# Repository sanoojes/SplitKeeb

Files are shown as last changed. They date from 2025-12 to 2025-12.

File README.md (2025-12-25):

# SplitKeeb

A split keyboard for my daily use.

## CAD

will be updated soon.

## PCB

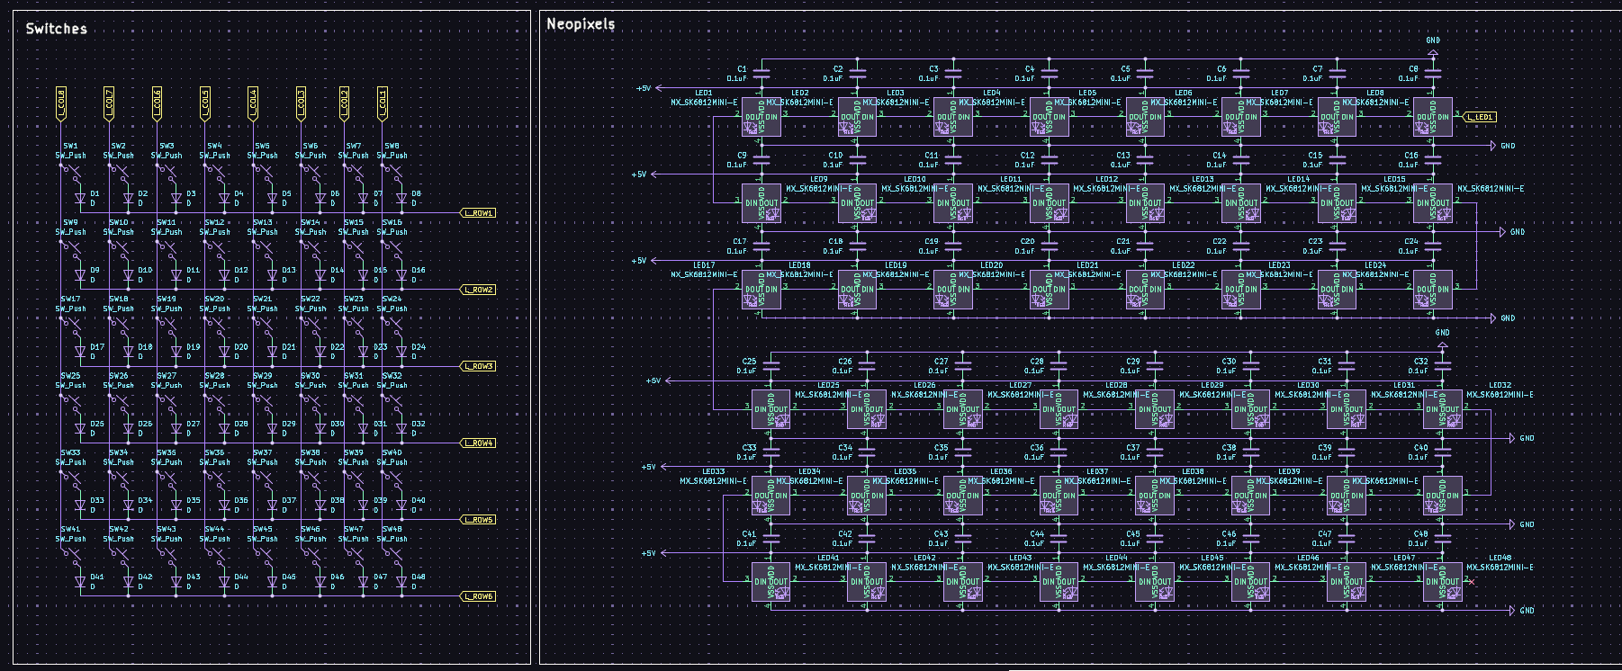
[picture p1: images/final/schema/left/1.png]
left 1
Schematics Left 
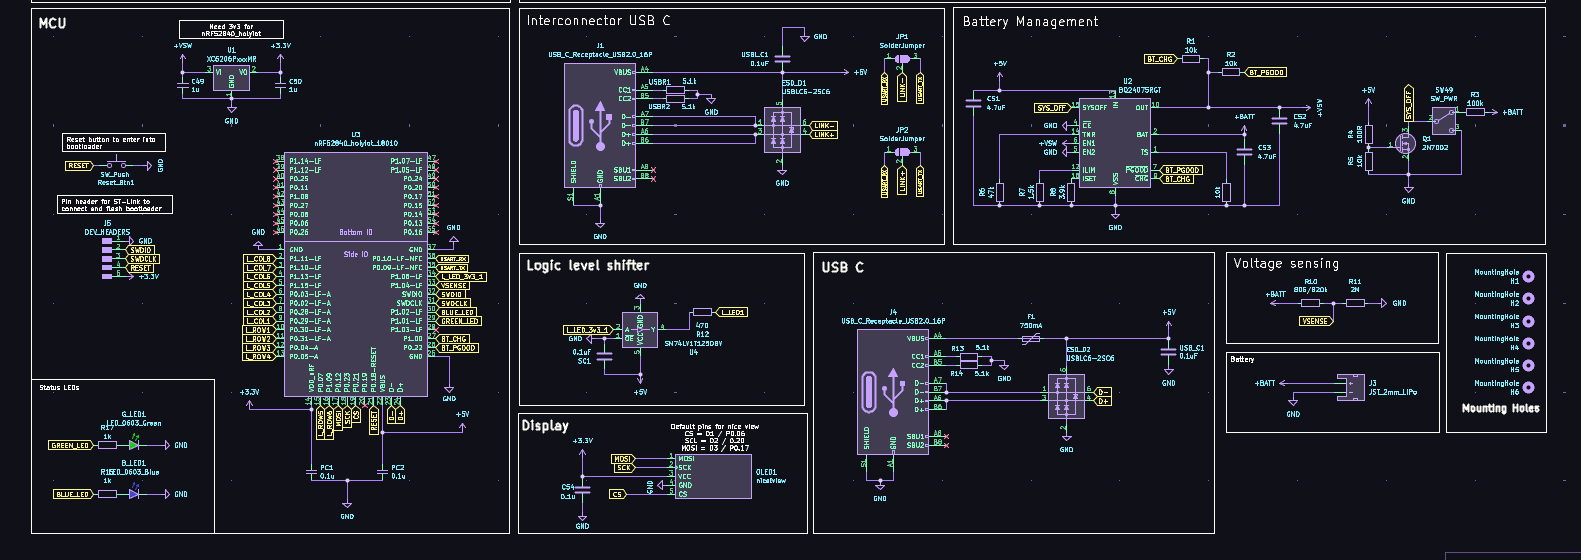
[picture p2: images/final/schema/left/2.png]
left 2


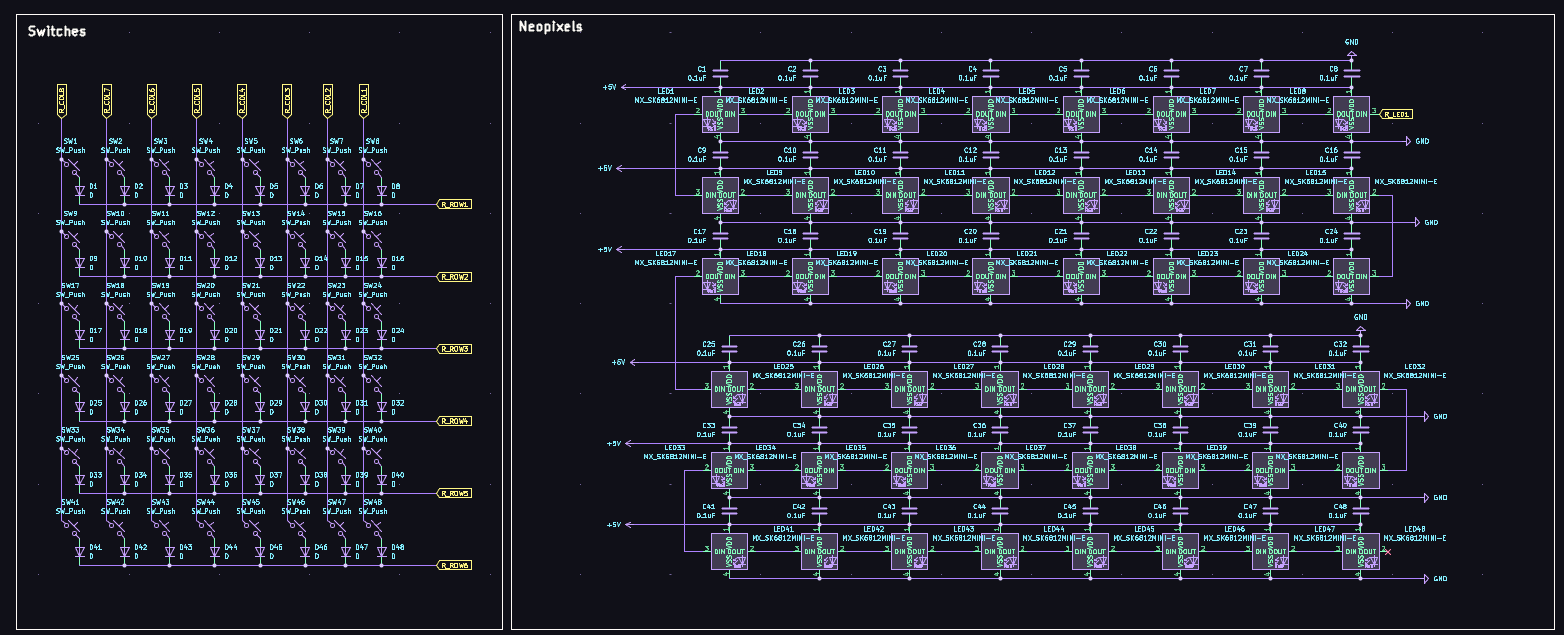
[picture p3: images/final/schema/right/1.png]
right 1
Schematics Right 
right 1

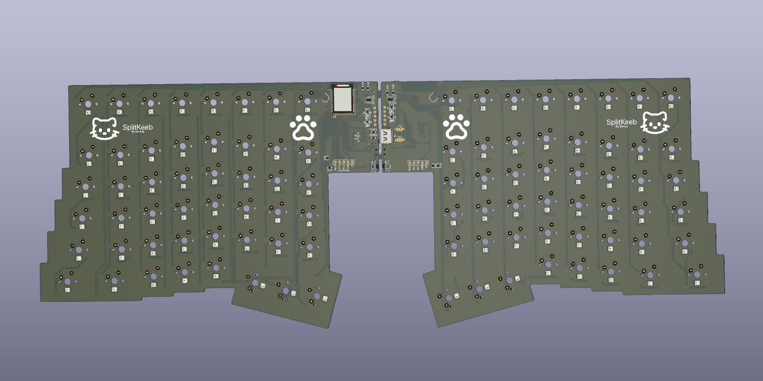
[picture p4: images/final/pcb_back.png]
pcb_back
Renders 
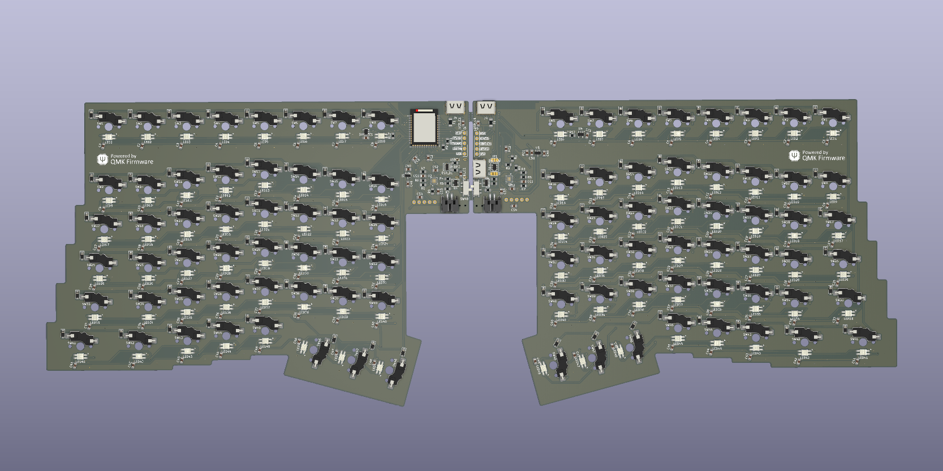
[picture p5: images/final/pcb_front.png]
pcb_front


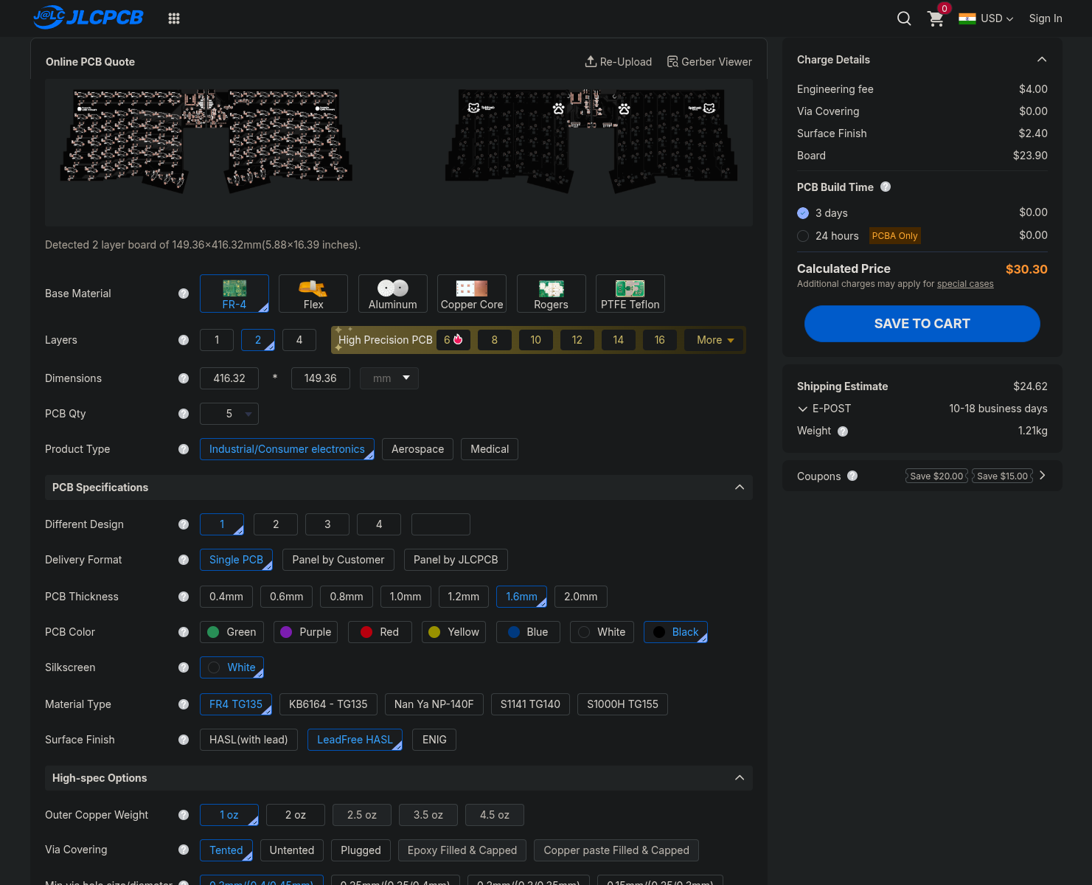
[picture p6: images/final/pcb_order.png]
pcb_order
JLC order

## Firmware

Firmware available at [firmware/](firmware/) firmware will be tweaked and
created after i get the materials/get approved.

### Bill of Materials

Checkout [BOM.csv](bom/SplitKeeb.csv)

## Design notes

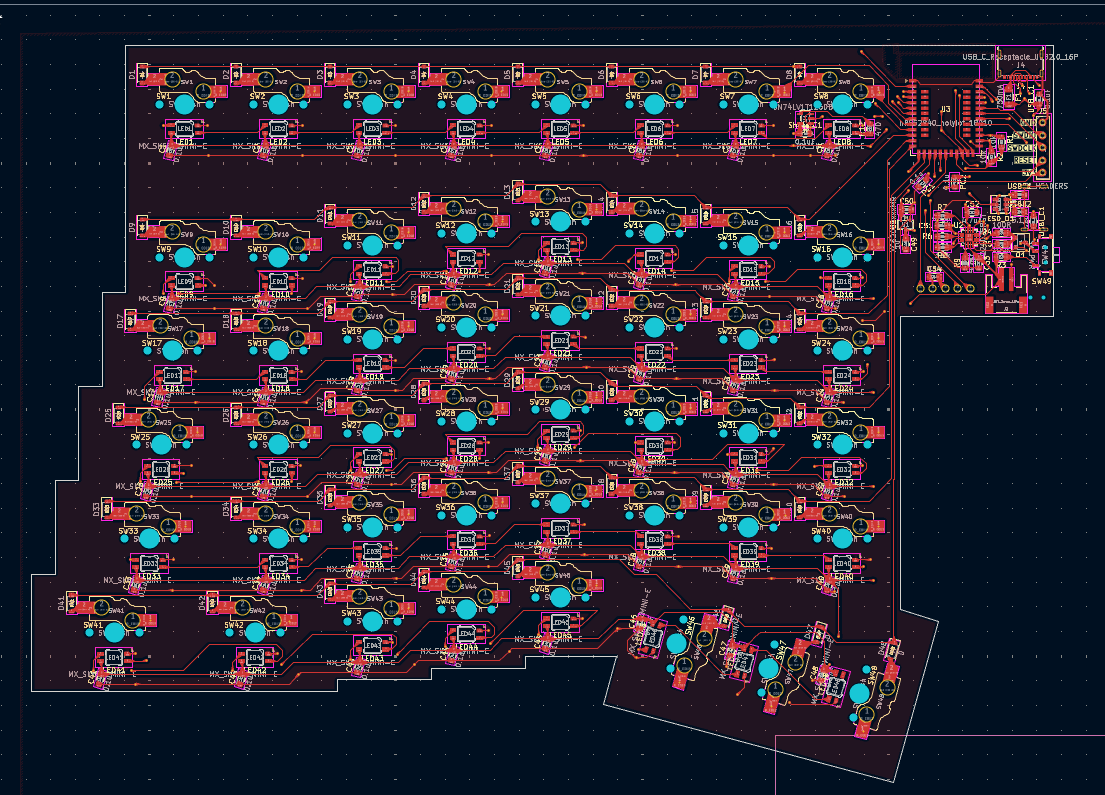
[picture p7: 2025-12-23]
images/day7/pcb2.png

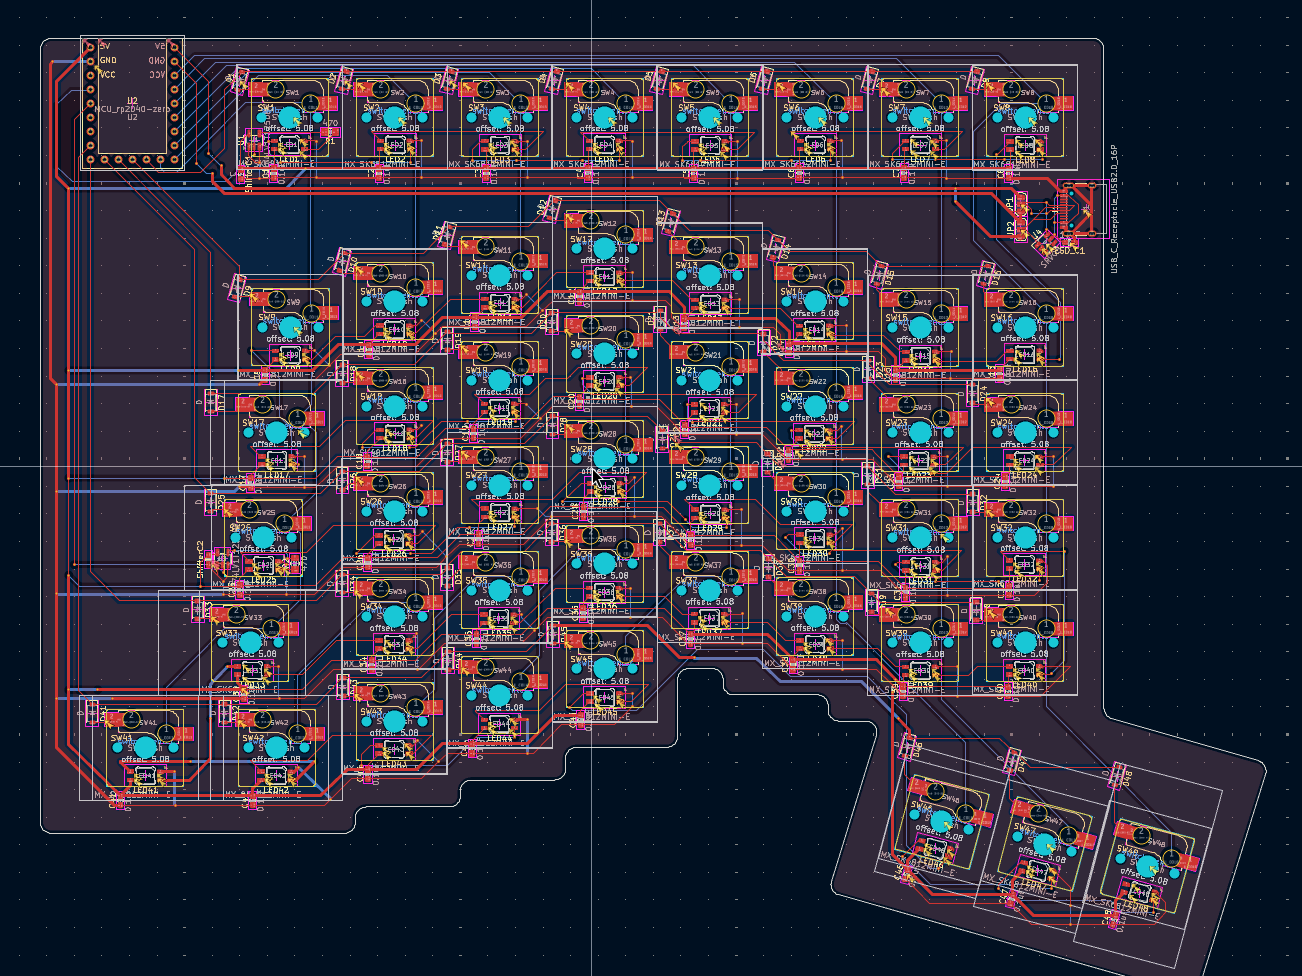
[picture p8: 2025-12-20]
images/day5/pcb_full.png

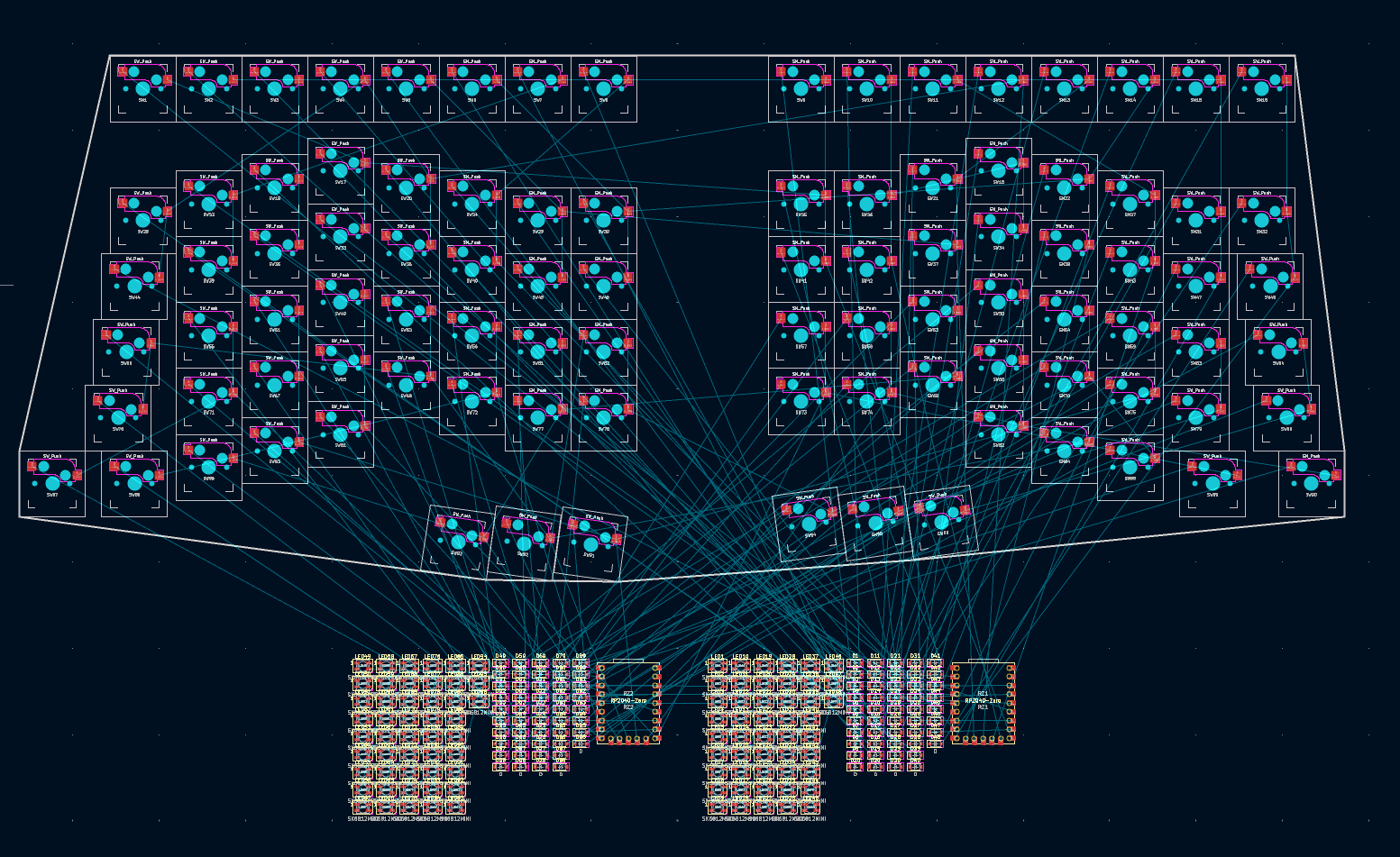
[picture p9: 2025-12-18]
images/day3/kbplacer.png

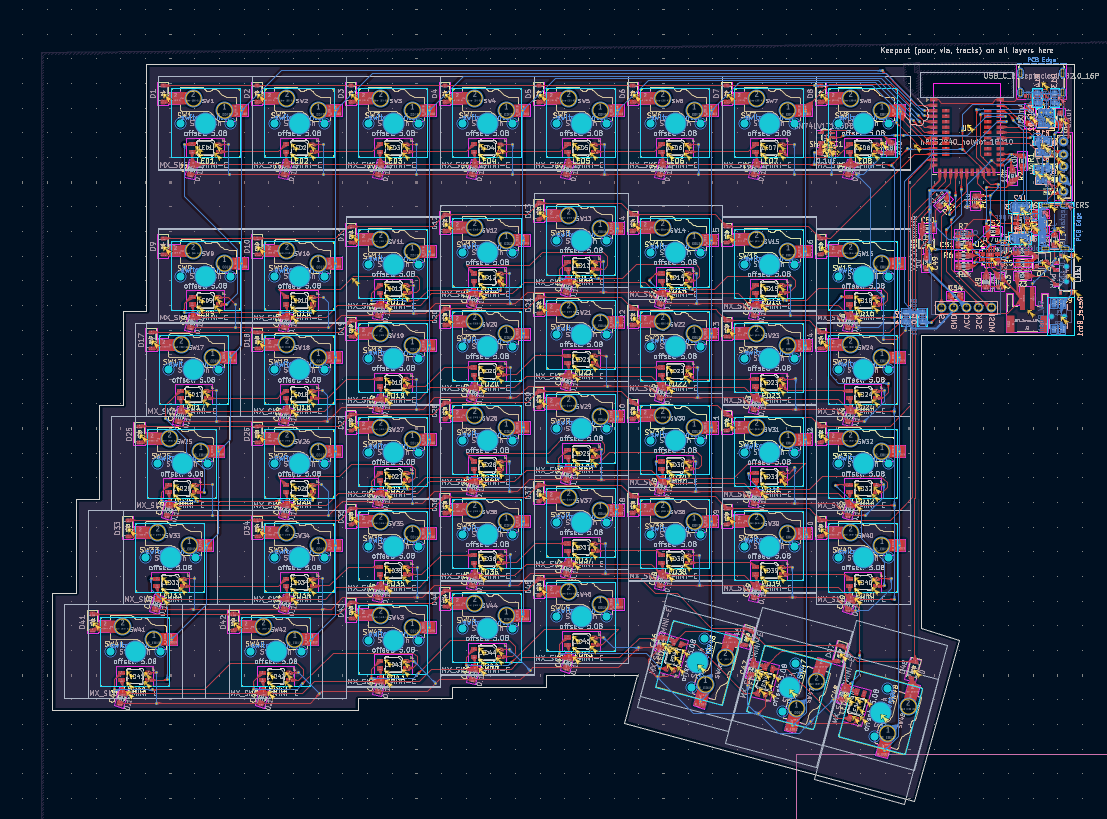
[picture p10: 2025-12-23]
images/day7/image.png

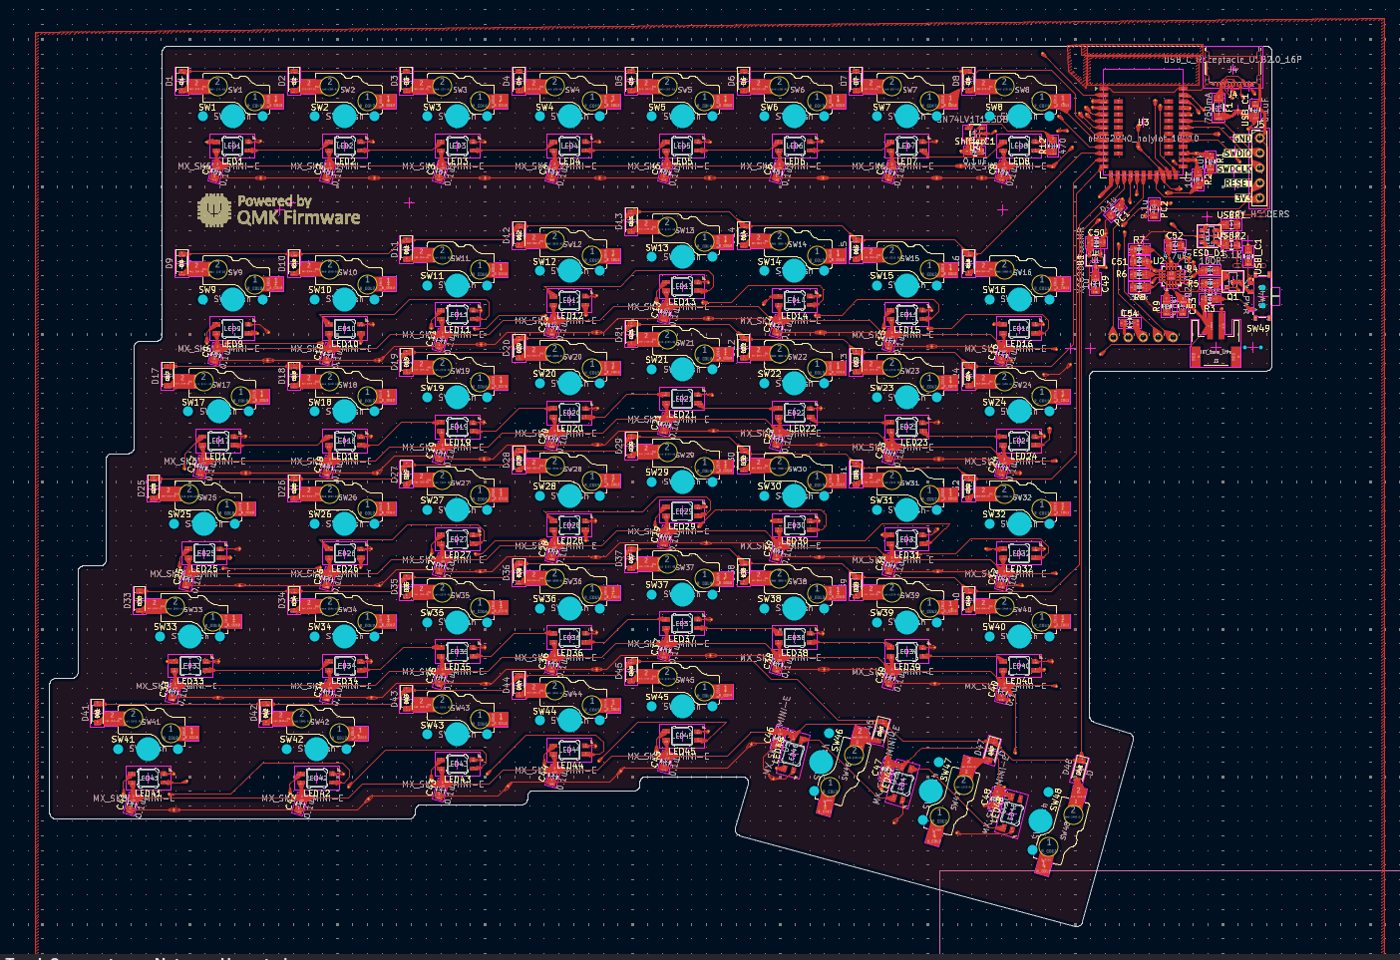
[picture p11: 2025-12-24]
images/day8/front_pcb.png

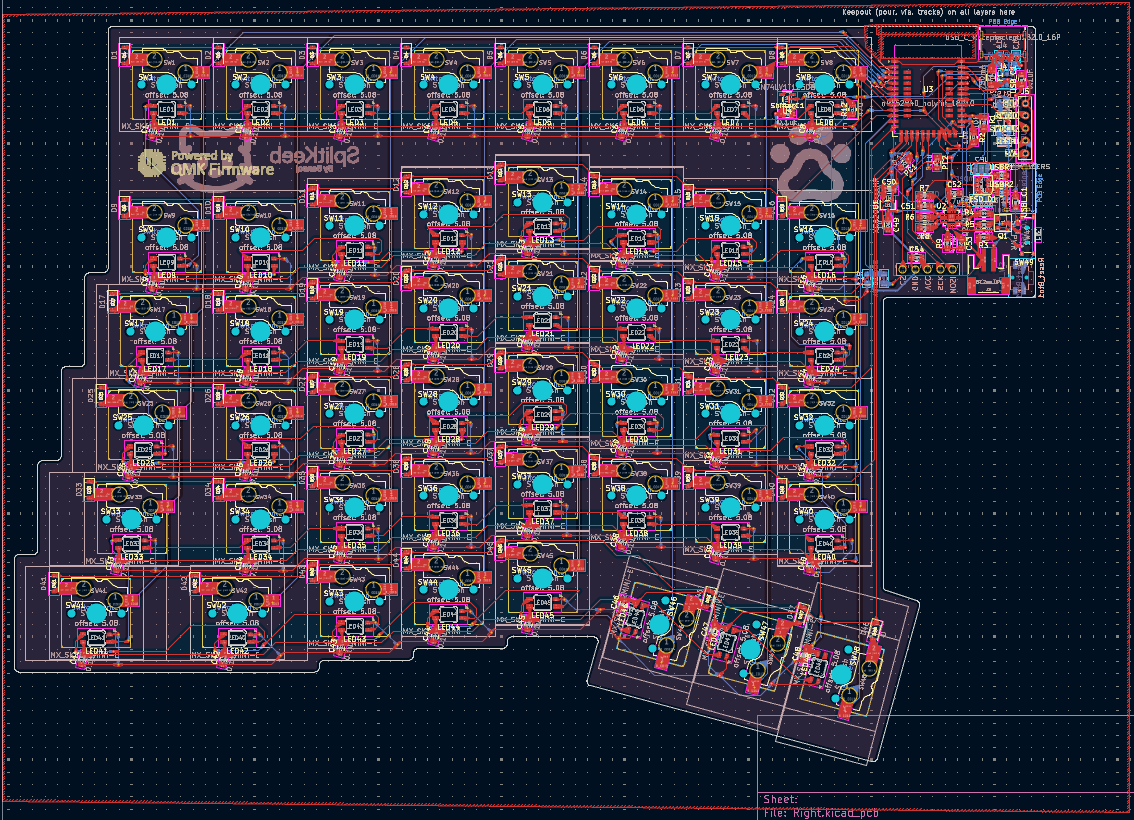
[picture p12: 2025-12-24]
images/day8/full_pcb.png

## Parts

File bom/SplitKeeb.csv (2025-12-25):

Item | Description | Note | Order Quantity | Unit Price | Total Price | URL | URL 2 | URL 3
0.1uF Capacitor | Decoupling Capacitors |  | 120 | ₹0.98 | ₹117.60 | https://robu.in/product/cl21b104kafnnne-samsang-25v-100nf-x7r-%c2%b110-0805-multilayer-ceramic-capacitors-mlcc-smd-smt-rohs/ | https://sharvielectronics.com/product/0-1uf-100nf-50v-capacitor-%c2%b110-tolerance-cc0805kkx7r9bb104-0805-package/
4.7uF Capacitor | Decoupling Capacitors |  | 8 | ₹0.80 | ₹6.40 | https://robu.in/product/cl21a475kpfnnne-samsang-10v-4-7uf-x5r-%C2%B110-0805-multilayer-ceramic-capacitors-mlcc-smd-smt-rohs/ | https://sharvielectronics.com/product/4-7uf-4700nf-25v-capacitor-%c2%b110-tolerance-0805x475k250ct-0805-package/
1uF Capacitor | Decoupling Capacitors |  | 8 | ₹0.70 | ₹5.60 | https://robu.in/product/cl21b105kofnfne-samsang-16v-1uf-x7r-%c2%b110-0805-multilayer-ceramic-capacitors-mlcc-smd-smt-rohs/ | https://sharvielectronics.com/product/1uf-1000nf-50v-capacitor-%c2%b110-tolerance-cc0805kkx7r9bb105-0805-package/
100 Ohm Resistor | Resistor |  | 4 | ₹0.72 | ₹2.88 | https://robu.in/product/ac0805fr-07100rl-yageo-res-thick-film-0805-100-ohm-1-0-125w1-8w-%C2%B1100ppm-c-pad-smd-t-r-automotive-aec-q200/ | https://sharvielectronics.com/product/100-ohm-1-8-watt-resistor-5-tolerance-rc0805jr-07100rl-0805-package/
1k Ohm Resistor | Resistor |  | 6 | ₹0.72 | ₹4.32 | https://robu.in/product/ac0805fr-071kl-yageo-res-thick-film-0805-1k-ohm-1-0-125w1-8w-%C2%B1100ppm-c-pad-smd-t-r-automotive-aec-q200/ | https://sharvielectronics.com/product/1k-ohm-1-8-watt-resistor-1-tolerance-0805s8f1001t5e-0805-package/
1.5K Ohm Resistor | Resistor |  | 4 | ₹0.31 | ₹1.24 | https://robu.in/product/ac0805fr-071k5l-yageo-res-thick-film-0805-1-5k-ohm-1-0-125w1-8w-%C2%B1100ppm-c-pad-smd-t-r-automotive-aec-q200/ | https://sharvielectronics.com/product/1-5k-ohm-1-8-watt-resistor-1-tolerance-0805w8f1501t5e-0805-package/
5.1k Ohm Resistor | Resistor |  | 6 | ₹1.27 | ₹7.62 | https://robu.in/product/af0805fr-075k1l-yageo-5-1k%cf%89-%c2%b11-125mw-thick-film-%c2%b1100ppm-%e2%84%83-0805-chip-resistor-surface-mount-rohs/ | https://sharvielectronics.com/product/5-1k-ohm-1-8-watt-resistor-1-tolerance-0805s8f5101t5e-0805-package/
10k Ohm Resistor | Resistor |  | 10 | ₹0.72 | ₹7.20 | https://robu.in/product/ac0805fr-0710kl-yageo-res-thick-film-0805-10k-ohm-1-0-125w1-8w-%C2%B1100ppm-c-pad-smd-t-r-automotive-aec-q200/ | https://sharvielectronics.com/product/10k-ohm-1-8-watt-resistor-1-tolerance-rc0805fr-0710kl-0805-package/
47K Ohm Resistor | Resistor |  | 3 | ₹0.29 | ₹0.87 | https://robu.in/product/ac0805fr-0747kl-yageo-res-thick-film-0805-47k-ohm-1-0-125w1-8w-%C2%B1100ppm-c-pad-smd-t-r-automotive-aec-q200/ | https://sharvielectronics.com/product/47k-ohm-1-8-watt-resistor-1-tolerance-rct0547kf-lf-0805-package/
100k Ohm Resistor | Resistor |  | 4 | ₹0.54 | ₹2.16 | https://robu.in/product/yageo-100k-ohm-1-2w-0805-surface-mount-resistor-pack-of-50/ | https://sharvielectronics.com/product/100k-ohm-1-8-watt-resistor-1-tolerance-0805w8f1003t5e-0805-package/
3.9k Ohm Resistor | Resistor |  | 4 | ₹0.15 | ₹0.60 | https://robu.in/product/rc0805fr-073k9l-yageo-res-thick-film-0805-3-9k-ohm-1-0-125w1-8w-%C2%B1100ppm-c-pad-smd-t-r/ | https://sharvielectronics.com/product/3-9k-ohm-1-4w-resistor-pack-of-20-smd-0805/
820k Ohm Resistor | Resistor |  | 4 | ₹0.32 | ₹1.28 | https://robu.in/product/ac0805fr-07820kl-yageo-res-thick-film-0805-820k-ohm-1-0-125w1-8w-%C2%B1100ppm-c-pad-smd-t-r-automotive-aec-q200/ | https://sharvielectronics.com/product/820k-ohm-1-4w-resistor-pack-of-20-smd-0805/
2M Ohm Resistor | Resistor |  | 4 | ₹0.65 | ₹2.60 | https://robu.in/product/ac0805fr-072ml-yageo-res-thick-film-0805-2m-ohm-1-0-125w1-8w-%C2%B1100ppm-c-pad-smd-t-r-automotive-aec-q200/ | https://robu.in/product/0805w8j0205t5e-uniohm-royal-ohm-125mw-thick-film-resistors-150v-%c2%b1100ppm-%e2%84%83-%c2%b15-2m%cf%89-0805-chip-resistor-surface-mou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
470 Ohm Resistor | Resistor |  | 4 | ₹0.28 | ₹1.12 | https://robu.in/product/ac0805fr-07470rl-yageo-res-thick-film-0805-470-ohm-1-0-125w1-8w-%C2%B1100ppm-c-pad-smd-t-r-automotive-aec-q200/ | https://sharvielectronics.com/product/470-ohm-1-8-watt-resistor-1-tolerance-0805w8f4700t5e-0805-package/
LED 0603 Blue | LED |  | 3 | ₹3.21 | ₹9.63 | https://robu.in/product/ltst-c193tbkt-5a-lite-on-5ma-15mcd-water-clear-20%e2%84%8380%e2%84%83-465nm475nm-blue-130-76mw-2-8v-0603-led-indication-discrete-rohs/ | https://sharvielectronics.com/product/blue-smd-led-19-21-bhc-an1p2-3t-0603-package/
LED 0603 Green | LED |  | 3 | ₹3.00 | ₹9.00 | https://robu.in/product/19-217-r6c-al1m2vy-3t-everlight-green-528nm-led-indication-discrete-3-3v-0603-1608-metric/ | https://sharvielectronics.com/product/green-smd-led-19-21sygc-s530-e2-tr8-0603-package/
BQ24075RGTT | Battery Management |  | 2 | ₹226.00 | ₹452.00 | https://robu.in/product/bq24075rgtt-texas-instruments-vqfn-16-ep3x3-battery-management-rohs/
HolyIOT 18010 | Microcontroller |  | 2 | ₹979.00 | ₹1,958.00 | https://robu.in/product/holyiot-18010-nrf52840-chipset-ble-module/
MF-NSMF110-2 | Fuse |  | 4 | ₹11.00 | ₹44.00 | https://robu.in/product/sl1206110-techfuse-6v-50a-1-1a-2-2a-1206-resettable-rohs/
MSK12C02-HB | Slide Switch |  | 2 | ₹8.00 | ₹16.00 | https://robu.in/product/msk12c02-hb-shou-han-horizontal-attachment-50ma-single-pole-double-throw-spdt-12v-10000-times-black-smd-slide-switches-rohs/
SN74LV1T125DBVR | Logic Level Shifter / Logic Buffer |  | 2 | ₹38.06 | ₹76.12 | https://robu.in/product/sn74lv1t125dbvr-texas-instruments-buffer-74lv1t125-1-6-v-to-5-5-v-sot-23-5/ | https://www.digikey.in/en/products/detail/texas-instruments/SN74LV1T125DBVR/4555571/
XC6206P332MR-G | Voltage Regulator |  | 5 | ₹46.00 | ₹230.00 | https://www.digikey.in/en/products/detail/torex-semiconductor-ltd/XC6206P332MR-G/7386004 | https://sharvielectronics.com/product/xc6206p332mr-g-3-3v-200ma-low-esr-cap-compatible-positive-voltage-regulator-sot-23-3-package/
USBLC6-2SC6 | ESD Protection |  | 6 | ₹31.87 | ₹191.22 | https://www.digikey.in/en/products/detail/stmicroelectronics/USBLC6-2SC6/1040559 | http://robu.in/product/usblc6-2sc6-stmicroelectronics-usblc6-2sc6-esd-protection-device-17-v-sot-23-6-pins-usblc/
1N4148W-T4 Diode (SOD-123) | Diode |  | 110 | ₹2.00 | ₹220.00 | https://stackskb.com/store/1n4148-sod-123-smd-diode/ | https://sharvielectronics.com/product/1n4148w-t4-high-speed-fast-switching-diode-sod-123-package/
Gateron Hotswap Sockets | Hotswap Sockets |  | 110 | ₹10.00 | ₹1,100.00 | https://stackskb.com/store/gateron-hotswap-sockets/
Cherry MX2A Switch Set | Cherry MX Switches | Sold as 110 Switch Pack | 110 | ₹36.35 | ₹3,999.00 | https://keychron.in/product/cherry-mx2a-switch-set/ | https://meckeys.com/shop/accessories/keyboard-accessories/key-switches/cherry-mx2a-switch/
Keycap Set |  |  | 1 | ₹2,199.00 | ₹2,199.00 | https://curiositycaps.in/products/blackberry
Coiled Cable |  |  | 1 | ₹1,699.00 | ₹1,699.00 | https://keychron.in/product/coiled-type-c-cable/
Coiled Cable |  | Need more research (will find cheaper ones) | 1 | ₹2,500.00 | ₹2,500.00 | https://keychron.in/product/keychron-premium-coiled-aviator-cable/ | https://keychron.in/product/coiled-type-c-cable/
SK6812MINI-E | RGB Lights | Am not sure about this one. | 120 | ₹25.00 | ₹3,000.00 | https://shop.beekeeb.com/products/sk6812mini-e | https://www.amazon.in/Kqcibz-Similar-WS2812B-Individually-Addressable/dp/B0D5LGQ629
nice!view | OLED Screen |  | 2 | ₹2,100.00 | ₹4,200.00 | https://shop.beekeeb.com/products/nice-view-with-sockets-power-saving-display-for-wireless-split-keyboard | https://ergokeyboard.sg/products/nice-view-lcd-display
2N7002 | SOT-23 MOSFET |  | 4 | ₹11.53 | ₹46.12 | https://sharvielectronics.com/product/2n7002-60v-300ma-n-channel-mosfet-sot-23-package/
USB C Female | USB C Receptacle TYPE-C-31-M-23-Hroparts |  | 2 | ₹65.00 | ₹130.00 | https://robu.in/product/type-c-31-m-23-hroparts-1-surface-mount-right-angle-16p-female-55%e2%84%8385%e2%84%83-type-c-smd-usb-connectors-rohs/
JST Male | JST Pin for the Battery |  | 2 | ₹11.00 | ₹22.00 | https://robu.in/product/ph-02y-2mm-2-pin-female-housing-connector-with-300mm-wire28-awg
JST 2mm | JST Pin for connecting Battery |  | 2 | ₹40.00 | ₹80.00 | https://robu.in/product/s2b-ph-sm4-tblfsn-jst-1x2p-2p-ph-tin-2-25%e2%84%8385%e2%84%83-2a-1-2mm-copper-alloy-horizontal-attachment-smdp2mmsurface-mount%ef%bc%8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
3.7v Battery |  |  | 2 | ₹438.00 | ₹876.00 | https://robu.in/product/1500mah-pcm-protected-micro-li-po-battery/
DEVELOPMENT KIT
Raspberry Pi Pico 2W | Microcontroller board, For Flashing firmware to the HolyIOT 18010 |  | 1 | ₹696.00 | ₹696.00 | https://robu.in/product/raspberry-pi-pico-2-w/ | https://www.raspberrypi.com/products/raspberry-pi-pico-2/
Breadboard |  |  | 1 | ₹32.00 | ₹32.00 | https://robu.in/product/solderless-400-pin-breadboard-normal-quality-without-packing/ | https://robu.in/product/mb102-830-points-solderless-prototype-pcb-breadboard-high-quality/
Jumper Cable | Male to Female |  | 1 | ₹38.00 | ₹38.00 | https://robu.in/product/male-to-female-jumper-wires-40pcs-20cm/
Jumper Cable | Male to Male |  | 1 | ₹41.00 | ₹41.00 | https://robu.in/product/male-to-male-jumper-wires-40pcs-20cm/
Expected PCB Price | (with shipping) | 50-60 USD |  |  | ₹5,030.00
TOTAL |  |  |  |  | ₹29,055.58
Expected Total with Shipping |  | Added 3000rs for shipping, this value will increase or decrease |  |  | ₹32,055.58
Expected Total in USD |  | 1 INR = 0.012 |  |  | $384.67

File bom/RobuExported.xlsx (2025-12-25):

MPN | Qty | Brand | Name | SKU | Stock Status | Total Price | Unit Price
CL21B104KAFNNNE | 120 | Samsung | CL21B104KAFNNNE-Samsung-25V 100nF X7R ±10% 0805 Multilayer Ceramic Capacitors MLCC - SMD/SMT ROHS | R172257 | In Stock | 117.6 | 0.98
CL21A475KPFNNNE | 8 | Samsung | CL21A475KPFNNNE-Samsung-10V 4.7uF X5R ±10% 0805 Multilayer Ceramic Capacitors MLCC - SMD/SMT ROHS | R172239 | In Stock | 6.24 | 0.78
CL21B105KOFNFNE | 8 | Samsung | CL21B105KOFNFNE-Samsung-16V 1uF X7R ±10% 0805 Multilayer Ceramic Capacitors MLCC - SMD/SMT ROHS | R172255 | In Stock | 5.52 | 0.69
AC0805FR-07100RL | 4 | Yageo | AC0805FR-07100RL-YAGEO-Res Thick Film 0805 100 Ohm 1% 0.125W(1/8W) ±100ppm/°C Pad SMD T/R Automotive AEC-Q200 | R136906 | In Stock | 2.88 | 0.72
AC0805FR-071KL | 6 | Yageo | AC0805FR-071KL-YAGEO-Res Thick Film 0805 1K Ohm 1% 0.125W(1/8W) ±100ppm/°C Pad SMD T/R Automotive AEC-Q200 | R143570 | In Stock | 4.32 | 0.72
AC0805FR-071K5L | 4 | Yageo | AC0805FR-071K5L-YAGEO-Res Thick Film 0805 1.5K Ohm 1% 0.125W(1/8W) ±100ppm/°C Pad SMD T/R Automotive AEC-Q200 | R143534 | In Stock | 1.24 | 0.31
AF0805FR-075K1L | 6 | Yageo | AF0805FR-075K1L-Yageo -5.1kΩ ±1% 125mW Thick Film ±100ppm/℃ 0805 Chip Resistor - Surface Mount ROHS | R218648 | In Stock | 7.62 | 1.27
AC0805FR-0710KL | 10 | Yageo | AC0805FR-0710KL-YAGEO-Res Thick Film 0805 10K Ohm 1% 0.125W(1/8W) ±100ppm/°C Pad SMD T/R Automotive AEC-Q200 | R143489 | In Stock | 7.2 | 0.72
AC0805FR-0747KL | 4 | Yageo | AC0805FR-0747KL-YAGEO-Res Thick Film 0805 47K Ohm 1% 0.125W(1/8W) ±100ppm/°C Pad SMD T/R Automotive AEC-Q200 | R143573 | In Stock | 1.12 | 0.28
 | 4 | Yageo | Yageo 100k Ohm 1/2W 0805 Surface Mount Resistor | 872080 | In Stock | 2.16 | 0.54
RC0805FR-073K9L | 4 | Yageo | RC0805FR-073K9L-YAGEO-Res Thick Film 0805 3.9K Ohm 1% 0.125W(1/8W) ±100ppm/°C Pad SMD T/R | R135910 | In Stock | 0.6 | 0.15
AC0805FR-07820KL | 4 | Yageo | AC0805FR-07820KL-YAGEO-Res Thick Film 0805 820K Ohm 1% 0.125W(1/8W) ±100ppm/°C Pad SMD T/R Automotive AEC-Q200 | R136963 | In Stock | 1.28 | 0.32
AC0805FR-072ML | 4 | Yageo | AC0805FR-072ML-YAGEO-Res Thick Film 0805 2M Ohm 1% 0.125W(1/8W) ±100ppm/°C Pad SMD T/R Automotive AEC-Q200 | R139402 | In Stock | 2.6 | 0.65
AC0805FR-07470RL | 4 | Yageo | AC0805FR-07470RL-YAGEO-Res Thick Film 0805 470 Ohm 1% 0.125W(1/8W) ±100ppm/°C Pad SMD T/R Automotive AEC-Q200 | R136946 | In Stock | 1.12 | 0.28
19-217/R6C-AL1M2VY/3T | 4 | EVERLIGHT | 19-217/R6C-AL1M2VY/3T-EVERLIGHT-Green 528nm LED Indication - Discrete 3.3V 0603 (1608 Metric) | R110503 | In Stock | 12 | 3
 | 4 | LITEON | LTST-C193TBKT-5A-Lite-On-5mA 15mcd Water Clear -20℃~+80℃ 465nm~475nm Blue 130° 76mW 2.8V 0603 LED Indication - Discrete ROHS | R250668 | In Stock | 12.84 | 3.21
BQ24075RGTT | 2 | Texas Instruments | BQ24075RGTT-Texas Instruments-VQFN-16-EP(3x3) Battery Management ROHS | R213777 | In Stock | 452 | 226
 | 2 | HOLYIOT | Holyiot 18010, Nrf52840 Long Range Chipset BLE Module | R228997 | In Stock | 1958 | 979
SL1206110 | 4 | TECHFUSE | SL1206110-TECHFUSE-6V 50A 1.1A 2.2A 1206 Resettable Fuse ROHS | R184450 | In Stock | 44 | 11
MSK12C02-HB | 2 | SHOUHAN | MSK12C02-HB-SHOU HAN-Horizontal attachment 50mA Single Pole Double Throw (SPDT) 12V 10,000 times Black SMD Slide Switches ROHS | R235199 | In Stock | 16 | 8
SN74LV1T125DBVR | 2 | Texas Instruments | SN74LV1T125DBVR-TEXAS INSTRUMENTS-Buffer, 74LV1T125, 1.6 V to 5.5 V, SOT-23-5 | R201746 | In Stock | 54 | 27
 |  |  |  |  |  | Subtotal: 2710.34

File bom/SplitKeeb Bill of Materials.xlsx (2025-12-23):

Item | Description | Note | Order Quantity | Unit Price | Total Price | Total Price with Tax | URL | URL 2 | URL 3
0.1uF Capacitor | Decoupling Capacitors |  | 120 | ₹1.00 | ₹120.00 | ₹141.60 | https://sharvielectronics.com/product/4-7uf-4700nf-25v-capacitor-%c2%b110-tolerance-0805x475k250ct-0805-package/
4.7uF Capacitor | Decoupling Capacitors |  | 20 | ₹2.12 | ₹42.40 | ₹50.03 | https://sharvielectronics.com/product/4-7uf-4700nf-25v-capacitor-%c2%b110-tolerance-0805x475k250ct-0805-package/
1uF Capacitor | Decoupling Capacitors |  | 10 | ₹2.16 | ₹21.60 | ₹25.49 | https://sharvielectronics.com/product/1uf-1000nf-50v-capacitor-%c2%b110-tolerance-cc0805kkx7r9bb105-0805-package/
100 Ohm Resistor | Resistor |  | 20 | ₹0.82 | ₹16.40 | ₹19.35 | https://sharvielectronics.com/product/100-ohm-1-8-watt-resistor-5-tolerance-rc0805jr-07100rl-0805-package/
1k Ohm Resistor | Resistor |  | 10 | ₹0.82 | ₹8.20 | ₹9.68 | https://sharvielectronics.com/product/1k-ohm-1-8-watt-resistor-1-tolerance-0805s8f1001t5e-0805-package/
1.5K Ohm Resistor | Resistor |  | 20 | ₹0.82 | ₹16.40 | ₹19.35 | https://sharvielectronics.com/product/1-5k-ohm-1-8-watt-resistor-1-tolerance-0805w8f1501t5e-0805-package/
5.1k Ohm Resistor | Resistor |  | 10 | ₹1.92 | ₹19.20 | ₹22.66 | https://sharvielectronics.com/product/5-1k-ohm-1-8-watt-resistor-1-tolerance-0805s8f5101t5e-0805-package/
10k Ohm Resistor | Resistor |  | 10 | ₹0.82 | ₹8.20 | ₹9.68 | https://sharvielectronics.com/product/10k-ohm-1-8-watt-resistor-1-tolerance-rc0805fr-0710kl-0805-package/
47K Ohm Resistor | Resistor |  | 20 | ₹0.82 | ₹16.40 | ₹19.35 | https://sharvielectronics.com/product/47k-ohm-1-8-watt-resistor-1-tolerance-rct0547kf-lf-0805-package/
100k Ohm Resistor | Resistor |  | 20 | ₹0.89 | ₹17.80 | ₹21.00 | https://sharvielectronics.com/product/100k-ohm-1-8-watt-resistor-1-tolerance-0805w8f1003t5e-0805-package/
3.9k Ohm Resistor | Resistor |  | 20 | ₹0.82 | ₹16.40 | ₹19.35 | https://sharvielectronics.com/product/3-9k-ohm-1-4w-resistor-pack-of-20-smd-0805/
820k Ohm Resistor | Resistor |  | 20 | ₹0.82 | ₹16.40 | ₹19.35 | https://sharvielectronics.com/product/820k-ohm-1-4w-resistor-pack-of-20-smd-0805/
470 Ohm Resistor | Resistor |  | 20 | ₹0.89 | ₹17.80 | ₹21.00 | https://sharvielectronics.com/product/470-ohm-1-8-watt-resistor-1-tolerance-0805w8f4700t5e-0805-package/
LED 0603 Blue | LED |  | 20 | ₹3.32 | ₹66.40 | ₹78.35 | https://sharvielectronics.com/product/blue-smd-led-19-21-bhc-an1p2-3t-0603-package/
LED 0603 Green | LED |  | 20 | ₹2.39 | ₹47.80 | ₹56.40 | https://sharvielectronics.com/product/green-smd-led-19-21sygc-s530-e2-tr8-0603-package/
XC6206P332MR-G | Voltage Regulator |  | 5 | ₹13.00 | ₹65.00 | ₹76.70 | https://sharvielectronics.com/product/xc6206p332mr-g-3-3v-200ma-low-esr-cap-compatible-positive-voltage-regulator-sot-23-3-package/
2M Ohm Resistor | Resistor |  | 4 | ₹0.12 | ₹0.48 | ₹0.48 | https://robu.in/product/0805w8j0205t5e-uniohm-royal-ohm-125mw-thick-film-resistors-150v-%c2%b1100ppm-%e2%84%83-%c2%b15-2m%cf%89-0805-chip-resistor-surface-mou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
BQ24075RGTT | Battery Management |  | 2 | ₹226.00 | ₹452.00 | ₹452.00 | https://robu.in/product/bq24075rgtt-texas-instruments-vqfn-16-ep3x3-battery-management-rohs/
HolyIOT 18010 | Microcontroller |  | 2 | ₹979.00 | ₹1958.00 | ₹1958.00 | https://robu.in/product/holyiot-18010-nrf52840-chipset-ble-module/
MF-NSMF110-2 | Fuse |  | 4 | ₹3.80 | ₹15.20 | ₹15.20 | https://robu.in/product/1-month-warranty-1113/
MSK12C02-HB | Slide Switch |  | 2 | ₹8.00 | ₹16.00 | ₹16.00 | https://robu.in/product/msk12c02-hb-shou-han-horizontal-attachment-50ma-single-pole-double-throw-spdt-12v-10000-times-black-smd-slide-switches-rohs/
SN74LV1T125DBVR | Logic Level Shifter / Logic Buffer |  | 2 | ₹38.06 | ₹76.12 | ₹76.12 | https://www.digikey.in/en/products/detail/texas-instruments/SN74LV1T125DBVR/4555571/ | https://robu.in/product/sn74lv1t125dbvr-texas-instruments-buffer-74lv1t125-1-6-v-to-5-5-v-sot-23-5/
USBLC6-2SC6 | ESD Protection (SOT23-6) |  | 6 | ₹31.87 | ₹191.22 | ₹191.22 | https://www.digikey.in/en/products/detail/stmicroelectronics/USBLC6-2SC6/1040559 | https://robu.in/product/usblc6-2sc6-ms-msksemi-4-5a-15v-150w-6v-5v-sot-23-6-esd-and-surge-protection-tvs-esd-rohs/
1N4148W-T4 Diode (SOD-123) | Diode |  | 110 | ₹2.00 | ₹220.00 | ₹259.60 | https://stackskb.com/product-category/parts/electronic-parts/ (https://sharvielectronics.com/product/1n4148w-t4-high-speed-fast-switching-diode-sod-123-package/) | https://sharvielectronics.com/product/1n4148w-t4-high-speed-fast-switching-diode-sod-123-package/
Kelowna Modular EVA Foam | Foam for the Switches |  | 120 | ₹12.50 | ₹1500.00 | ₹1500.00 | https://stackskb.com/store/kelowna-modular-foam-pack-of-120/
Gateron Hotswap Sockets | Hotswap Sockets |  | 110 | ₹10.00 | ₹1100.00 | ₹1100.00 | https://stackskb.com/store/gateron-hotswap-sockets/
Cherry MX2A Switch Set | Cherry MX Switches | Sold as 110 Switch Pack | 110 | ₹36.35 | ₹3999.00 | ₹3999.00 | https://keychron.in/product/cherry-mx2a-switch-set/ | https://meckeys.com/shop/accessories/keyboard-accessories/key-switches/cherry-mx2a-switch/
Coiled Cable |  |  | 2 | ₹2500.00 | ₹5000.00 | ₹5000.00 | https://keychron.in/product/keychron-premium-coiled-aviator-cable/ | https://keychron.in/product/coiled-type-c-cable/
SK6812MINI-E | RGB Lights | Am not sure about this one. | 120 | ₹25.00 | ₹3000.00 | ₹3000.00 | https://shop.beekeeb.com/products/sk6812mini-e | https://www.amazon.in/Kqcibz-Similar-WS2812B-Individually-Addressable/dp/B0D5LGQ629
nice!view | OLED Screen |  | 2 | ₹2100.00 | ₹4200.00 | ₹4200.00 | https://shop.beekeeb.com/products/nice-view-with-sockets-power-saving-display-for-wireless-split-keyboard | https://ergokeyboard.sg/products/nice-view-lcd-display
2N7002 | SOT-23 MOSFET |  | 4 | ₹11.53 | ₹46.12 | ₹54.42 | https://sharvielectronics.com/product/2n7002-60v-300ma-n-channel-mosfet-sot-23-package/
USB C Female | USB C Receptacle TYPE-C-31-M-23-Hroparts |  | 2 | ₹65.00 | ₹130.00 | ₹130.00 | https://robu.in/product/type-c-31-m-23-hroparts-1-surface-mount-right-angle-16p-female-55%e2%84%8385%e2%84%83-type-c-smd-usb-connectors-rohs/
JST Male | JST Pin for the Battery |  | 2 | ₹11.00 | ₹22.00 | ₹22.00 | https://robu.in/product/ph-02y-2mm-2-pin-female-housing-connector-with-300mm-wire28-awg
JST 2mm | JST Pin for connecting Battery |  | 2 | ₹40.00 | ₹80.00 | ₹80.00 | https://robu.in/product/s2b-ph-sm4-tblfsn-jst-1x2p-2p-ph-tin-2-25%e2%84%8385%e2%84%83-2a-1-2mm-copper-alloy-horizontal-attachment-smdp2mmsurface-mount%ef%bc%8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
3.7v Battery |  |  | 2 | ₹438.00 | ₹876.00 | ₹876.00 | https://robu.in/product/1500mah-pcm-protected-micro-li-po-battery/
DEVELOPMENT KIT
Raspberry Pi Pico 2W | Microcontroller board, For Flashing firmware to the HolyIOT 18010 |  | 1 | ₹696.00 | ₹696.00 | ₹696.00 | https://robu.in/product/raspberry-pi-pico-2-w/ | https://www.raspberrypi.com/products/raspberry-pi-pico-2/
Breadboard |  |  | 1 | ₹32.00 | ₹32.00 | ₹32.00 | https://robu.in/product/solderless-400-pin-breadboard-normal-quality-without-packing/ | https://robu.in/product/mb102-830-points-solderless-prototype-pcb-breadboard-high-quality/
Jumper Cable | Male to Female |  | 1 | ₹38.00 | ₹38.00 | ₹38.00 | https://robu.in/product/male-to-female-jumper-wires-40pcs-20cm/
Jumper Cable | Male to Male |  | 1 | ₹41.00 | ₹41.00 | ₹41.00 | https://robu.in/product/male-to-male-jumper-wires-40pcs-20cm/
TOTAL |  |  |  |  | ₹24205.54 | ₹24346.39
Expected Total with Shipping |  | Added 3000rs for shipping, this value will increase or decrease |  |  | ₹27205.54 | ₹27346.39
Expected Total in USD |  |  |  |  | $326.47 | $328.16
IMPORTANT NOTES
Some of the Components listed in website including Tax, some of them are not, so refer to the Total Price with Tax
Some of the Order Quantity has 5 or 10 more than needed to compensate with the Minimum Order Quanity of the Providers, This is cheaper than using different providers. Because of the shipping fees and price difference.

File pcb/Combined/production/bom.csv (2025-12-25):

Designator | Footprint | Quantity | Value | LCSC Part #
B_LED1_2, B_LED1 | 0603 | 2 | LED_0603_Blue
C1_2, C1, C10_2, C10, C11_2, C11, C12_2, C12, C13_2, C13, C14_2, C14, C15_2, C15, C16_2, C16, C17_2, C17, C18_2, C18, C19_2, C19, C2_2, C2, C20_2, C20, C21_2, C21, C22_2, C22, C23_2, C23, C24_2, C24, C25_2, C25, C26_2, C26, C27_2, C27, C28_2, C28, C29_2, C29, C3_2, C3, C30_2, C30, C31_2, C31, C32_2, C32, C33_2, C33, C34_2, C34, C35_2, C35, C36_2, C36, C37_2, C37, C38_2, C38, C39_2, C39, C4_2, C4, C40_2, C40, C41_2, C41, C42_2, C42, C43_2, C43, C44_2, C44, C45_2, C45, C46_2, C46, C47_2, C47, C48_2, C48, C5_2, C5, C6_2, C6, C7_2, C7, C8_2, C8, C9_2, C9, SC1, SHIFTERC1, USBI_C1_2, USBI_C1 | 0805 | 100 | 0.1uF
C49_2, C49, C50_2, C50 | 0805 | 4 | 1u
C51_2, C51, C52_2, C52, C53_2, C53 | 0805 | 6 | 4.7uF
C54_2, C54, PC1_2, PC1, PC2_2, PC2 | 0805 | 6 | 0.1u
D1_2, D1, D10_2, D10, D11_2, D11, D12_2, D12, D13_2, D13, D14_2, D14, D15_2, D15, D16_2, D16, D17_2, D17, D18_2, D18, D19_2, D19, D2_2, D2, D20_2, D20, D21_2, D21, D22_2, D22, D23_2, D23, D24_2, D24, D25_2, D25, D26_2, D26, D27_2, D27, D28_2, D28, D29_2, D29, D3_2, D3, D30_2, D30, D31_2, D31, D32_2, D32, D33_2, D33, D34_2, D34, D35_2, D35, D36_2, D36, D37_2, D37, D38_2, D38, D39_2, D39, D4_2, D4, D40_2, D40, D41_2, D41, D42_2, D42, D43_2, D43, D44_2, D44, D45_2, D45, D46_2, D46, D47_2, D47, D48_2, D48, D5_2, D5, D6_2, D6, D7_2, D7, D8_2, D8, D9_2, D9 | D_SOD-123 | 96 | D
ESD_D1_2, ESD_D1, ESD_D2_2, ESD_D2 | SOT-23-6 | 4 | USBLC6-2SC6
F1_2, F1 | 1206 | 2 | 750mA | C135341
G_LED1_2, G_LED1 | 0603 | 2 | LED_0603_Green
J1_2, J1, J4_2, J4 | USB_C_Receptacle_HRO_TYPE-C-31-M-23 | 4 | USB_C_Receptacle_USB2.0_16P
J3_2, J3 | JST_1x02_P2.0mm_Horizontal_SMD | 2 | JST_2mm_LiPo
J5_2, J5 | PinHeader_01x05_P2.54mm_Vertical_THT_D1mm | 2 | DEV_HEADERS
LED1_2, LED1, LED10_2, LED10, LED11_2, LED11, LED12_2, LED12, LED13_2, LED13, LED14_2, LED14, LED15_2, LED15, LED16_2, LED16, LED17_2, LED17, LED18_2, LED18, LED19_2, LED19, LED2_2, LED2, LED20_2, LED20, LED21_2, LED21, LED22_2, LED22, LED23_2, LED23, LED24_2, LED24, LED25_2, LED25, LED26_2, LED26, LED27_2, LED27, LED28_2, LED28, LED29_2, LED29, LED3_2, LED3, LED30_2, LED30, LED31_2, LED31, LED32_2, LED32, LED33_2, LED33, LED34_2, LED34, LED35_2, LED35, LED36_2, LED36, LED37_2, LED37, LED38_2, LED38, LED39_2, LED39, LED4_2, LED4, LED40_2, LED40, LED41_2, LED41, LED42_2, LED42, LED43_2, LED43, LED44_2, LED44, LED45_2, LED45, LED46_2, LED46, LED47_2, LED47, LED48_2, LED48, LED5_2, LED5, LED6_2, LED6, LED7_2, LED7, LED8_2, LED8, LED9_2, LED9 | LED_MX_6028R-ROT | 96 | MX_SK6812MINI-E
OLED1_2, OLED1 | nice_view | 2 | nice!view
Q1_2, Q1 | SOT-23 | 2 | 2N7002
R1_2, R1, R2_2, R2, R5_2, R5, R9_2, R9 | 0805 | 8 | 10k
R10_2, R10 | 0805 | 2 | 806/820k
R11_2, R11 | 0805 | 2 | 2M
R12_2, R12 | 0805 | 2 | 470
R13_2, R13, R14_2, R14, USBR1_2, USBR1, USBR2_2, USBR2 | 0805 | 8 | 5.1k
R15_2, R15, R17_2, R17 | 0805 | 4 | 1k
R3_2, R3 | 0805 | 2 | 100k
R4_2, R4 | 0805 | 2 | 100R
R6_2, R6 | 0805 | 2 | 47k
R7_2, R7 | 0805 | 2 | 1.5k
R8_2, R8 | 0805 | 2 | 3.9k
RESET_BTN1_2, RESET_BTN1 | Panasonic_EVQPUL_EVQPUC | 2 | SW_Push | C79175
SW1_2, SW1, SW10_2, SW10, SW11_2, SW11, SW12_2, SW12, SW13_2, SW13, SW14_2, SW14, SW15_2, SW15, SW16_2, SW16, SW18_2, SW18, SW19_2, SW19, SW2_2, SW2, SW20_2, SW20, SW21_2, SW21, SW22_2, SW22, SW23_2, SW23, SW24_2, SW24, SW26_2, SW26, SW27_2, SW27, SW28_2, SW28, SW29_2, SW29, SW3_2, SW3, SW30_2, SW30, SW31_2, SW31, SW32_2, SW32, SW34_2, SW34, SW35_2, SW35, SW36_2, SW36, SW37_2, SW37, SW38_2, SW38, SW39_2, SW39, SW4_2, SW4, SW40_2, SW40, SW43_2, SW43, SW44_2, SW44, SW45_2, SW45, SW5_2, SW5, SW6_2, SW6, SW7_2, SW7, SW8_2, SW8, SW9_2, SW9 | SW_MX_HS_KS-2P02B01-01_1u | 80 | SW_Push
SW17_2, SW17, SW46_2, SW46 | SW_MX_HS_KS-2P02B01-01_1.25u | 4 | SW_Push
SW25_2, SW25, SW41_2, SW41, SW42_2, SW42, SW47_2, SW47 | SW_MX_HS_KS-2P02B01-01_1.5u | 8 | SW_Push
SW33_2, SW33, SW48_2, SW48 | SW_MX_HS_KS-2P02B01-01_1.75u | 4 | SW_Push
SW49_2, SW49 | SW_MSK12C02-HB | 2 | SW_PWR
U1_2, U1 | SOT-23-3 | 2 | XC6206PxxxMR
U2_2, U2 | VQFN-16-1EP_3x3mm_P0.5mm_EP1.6x1.6mm | 2 | BQ24075RGT
U3_2, U3 | nRF52840_holyiot_18010 | 2 | nRF52840_holyiot_18010
U4_2, U4 | SOT-23-5 | 2 | SN74LV1T125DBV
USB_C1_2, USB_C1 | 0805 | 2 | 0.1uF | C307331

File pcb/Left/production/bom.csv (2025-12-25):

Designator | Footprint | Quantity | Value | LCSC Part #
B_LED1 | 0603 | 1 | LED_0603_Blue
C1, C10, C11, C12, C13, C14, C15, C16, C17, C18, C19, C2, C20, C21, C22, C23, C24, C25, C26, C27, C28, C29, C3, C30, C31, C32, C33, C34, C35, C36, C37, C38, C39, C4, C40, C41, C42, C43, C44, C45, C46, C47, C48, C5, C6, C7, C8, C9, SC1, USBI_C1 | 0805 | 50 | 0.1uF
C49, C50 | 0805 | 2 | 1u
C51, C52, C53 | 0805 | 3 | 4.7uF
C54, PC1, PC2 | 0805 | 3 | 0.1u
D1, D10, D11, D12, D13, D14, D15, D16, D17, D18, D19, D2, D20, D21, D22, D23, D24, D25, D26, D27, D28, D29, D3, D30, D31, D32, D33, D34, D35, D36, D37, D38, D39, D4, D40, D41, D42, D43, D44, D45, D46, D47, D48, D5, D6, D7, D8, D9 | D_SOD-123 | 48 | D
ESD_D1, ESD_D2 | SOT-23-6 | 2 | USBLC6-2SC6
F1 | 1206 | 1 | 750mA | C135341
G_LED1 | 0603 | 1 | LED_0603_Green
J1, J4 | USB_C_Receptacle_HRO_TYPE-C-31-M-23 | 2 | USB_C_Receptacle_USB2.0_16P
J3 | JST_1x02_P2.0mm_Horizontal_SMD | 1 | JST_2mm_LiPo
J5 | PinHeader_01x05_P2.54mm_Vertical_THT_D1mm | 1 | DEV_HEADERS
LED1, LED10, LED11, LED12, LED13, LED14, LED15, LED16, LED17, LED18, LED19, LED2, LED20, LED21, LED22, LED23, LED24, LED25, LED26, LED27, LED28, LED29, LED3, LED30, LED31, LED32, LED33, LED34, LED35, LED36, LED37, LED38, LED39, LED4, LED40, LED41, LED42, LED43, LED44, LED45, LED46, LED47, LED48, LED5, LED6, LED7, LED8, LED9 | LED_MX_6028R-ROT | 48 | MX_SK6812MINI-E
OLED1 | nice_view | 1 | nice!view
Q1 | SOT-23 | 1 | 2N7002
R1, R2, R5, R9 | 0805 | 4 | 10k
R10 | 0805 | 1 | 806/820k
R11 | 0805 | 1 | 2M
R12 | 0805 | 1 | 470
R13, R14, USBR1, USBR2 | 0805 | 4 | 5.1k
R15, R17 | 0805 | 2 | 1k
R3 | 0805 | 1 | 100k
R4 | 0805 | 1 | 100R
R6 | 0805 | 1 | 47k
R7 | 0805 | 1 | 1.5k
R8 | 0805 | 1 | 3.9k
RESET_BTN1 | Panasonic_EVQPUL_EVQPUC | 1 | SW_Push | C79175
SW1, SW10, SW11, SW12, SW13, SW14, SW15, SW16, SW18, SW19, SW2, SW20, SW21, SW22, SW23, SW24, SW26, SW27, SW28, SW29, SW3, SW30, SW31, SW32, SW34, SW35, SW36, SW37, SW38, SW39, SW4, SW40, SW43, SW44, SW45, SW5, SW6, SW7, SW8, SW9 | SW_MX_HS_KS-2P02B01-01_1u | 40 | SW_Push
SW17, SW46 | SW_MX_HS_KS-2P02B01-01_1.25u | 2 | SW_Push
SW25, SW41, SW42, SW47 | SW_MX_HS_KS-2P02B01-01_1.5u | 4 | SW_Push
SW33, SW48 | SW_MX_HS_KS-2P02B01-01_1.75u | 2 | SW_Push
SW49 | SW_MSK12C02-HB | 1 | SW_PWR
U1 | SOT-23-3 | 1 | XC6206PxxxMR
U2 | VQFN-16-1EP_3x3mm_P0.5mm_EP1.6x1.6mm | 1 | BQ24075RGT
U3 | nRF52840_holyiot_18010 | 1 | nRF52840_holyiot_18010
U4 | SOT-23-5 | 1 | SN74LV1T125DBV
USB_C1 | 0805 | 1 | 0.1uF | C307331

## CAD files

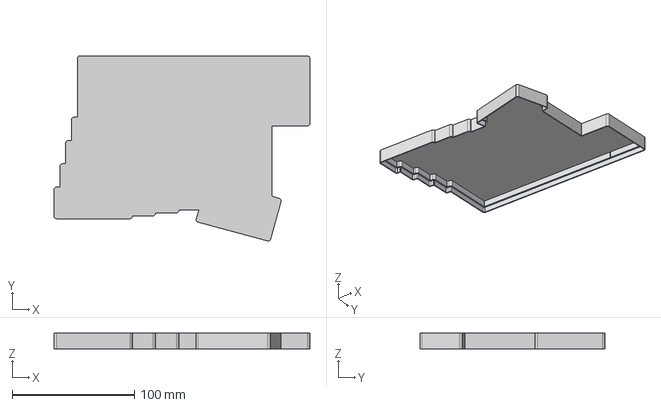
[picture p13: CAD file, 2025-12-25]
cad/Bottom_case.step
209.3 x 151.3 x 12.9 mm

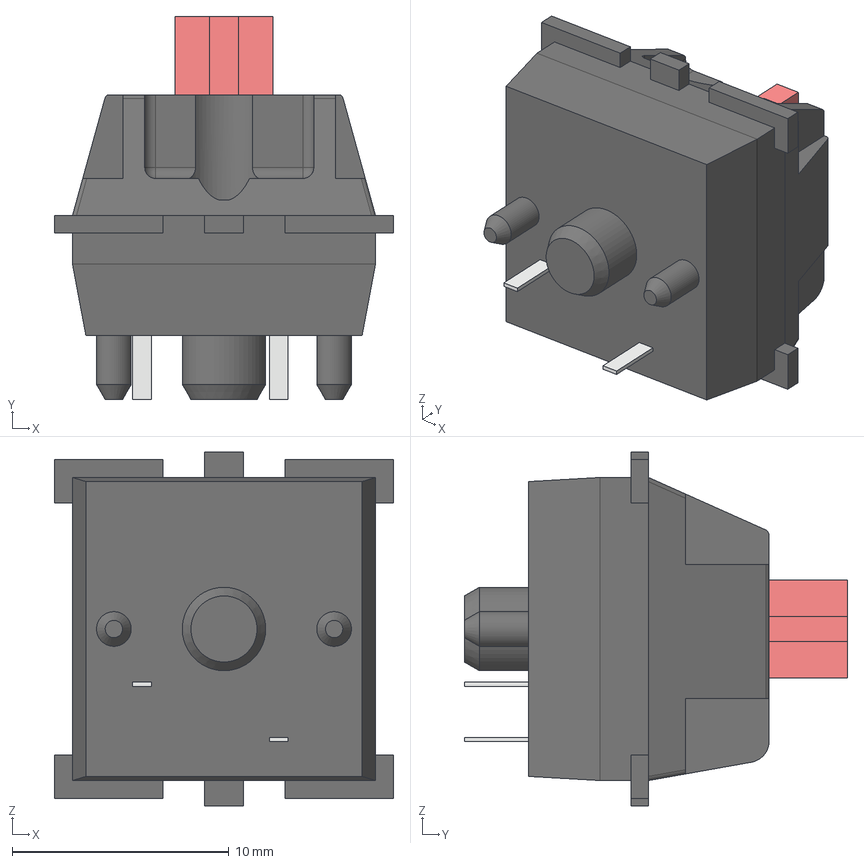
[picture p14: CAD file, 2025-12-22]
pcb/Left/3dmodels/switch.step
15.6 x 17.7 x 16.3 mm

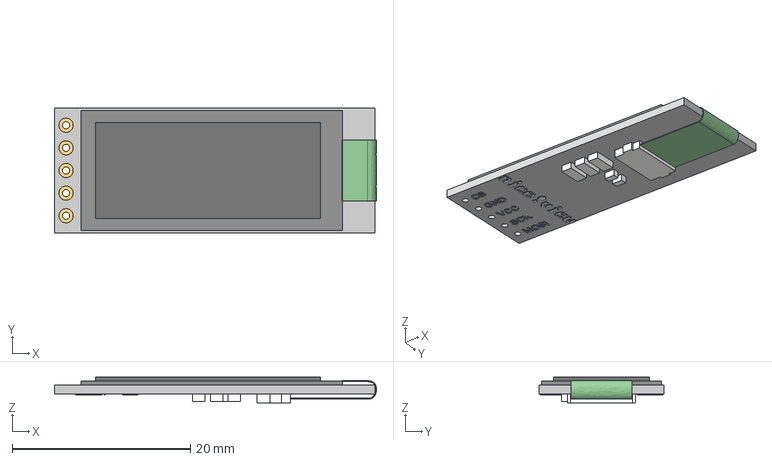
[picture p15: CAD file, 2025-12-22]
pcb/Right/3dmodels/nice!view.step
36.1 x 14.0 x 2.90 mm

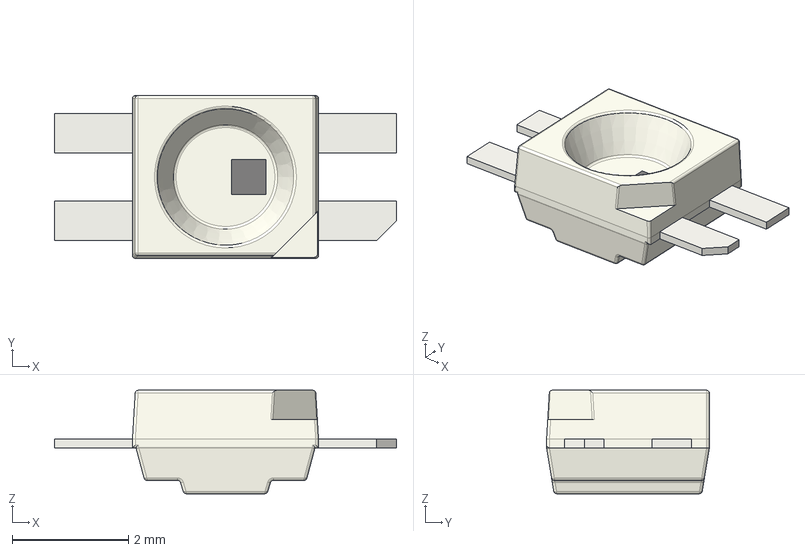
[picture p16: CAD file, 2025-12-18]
pcb/Left/3dmodels/LED_SK6812MINI-E.step
5.88 x 2.80 x 1.78 mm

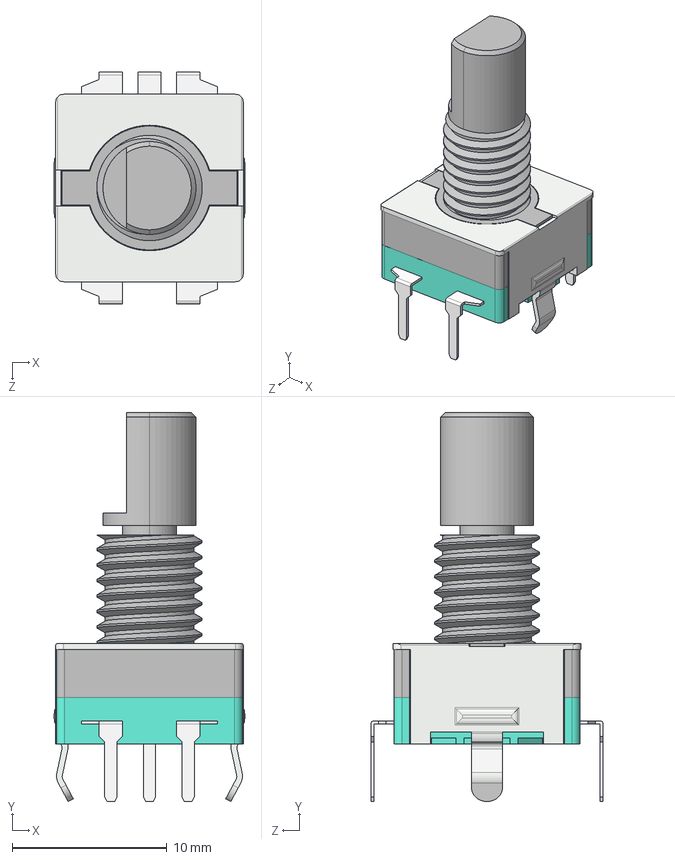
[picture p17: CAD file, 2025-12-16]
pcb/Left/3dmodels/rotary-encoder.STEP
12.3 x 25.1 x 15.0 mm

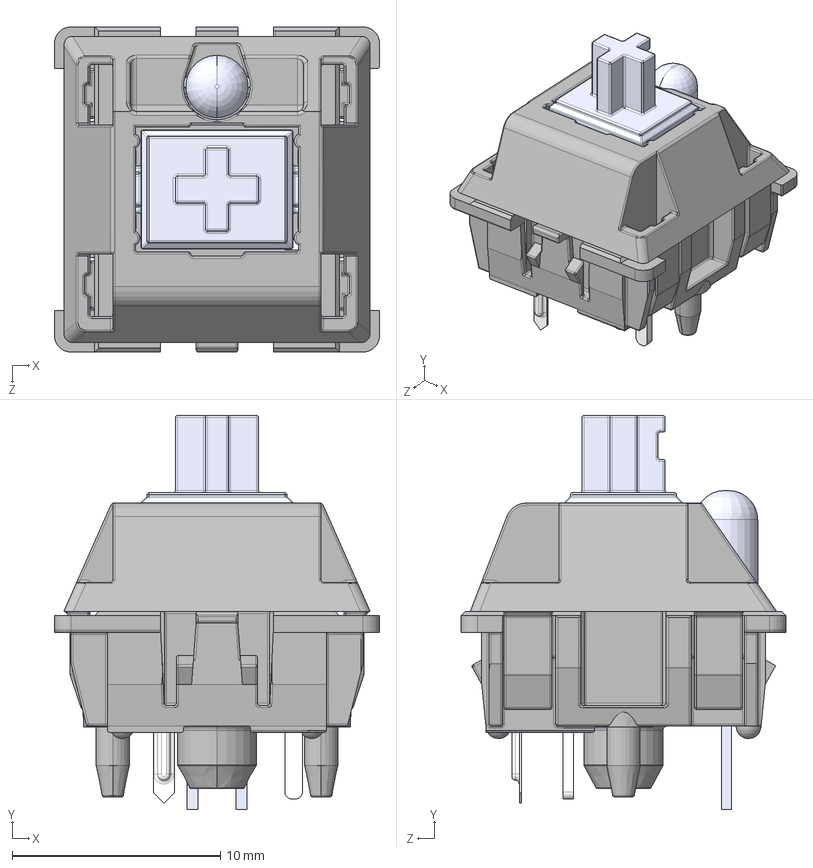
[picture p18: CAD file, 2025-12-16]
pcb/Right/3dmodels/MX .STEP
15.6 x 18.9 x 15.6 mm
MX 轴 按键′_ü___¨1
MX 轴 轴体áì_¨￠¨__
MX粣 拸簽LEDLEDLED
MX轴 轴体 底部 μ×2__默认_á2____è_
针脚___默认__è_

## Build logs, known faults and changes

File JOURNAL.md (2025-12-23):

# SplitKeeb Journey

## Day 1: Planning

Im officially committing to a build.

The plan is a split keyboard built around XIAO-nRF52840 controllers (for 2 sides
as in split keyboard guided project) a 5-column, 6-row layout (so 5x6 x2). I
want it to feel modern, so I’m going for addressable RGB, hotswappable MX
sockets, and Gateron 3.0 Red switches. Firmware-wise, I’m choosing ZMK.

So the Materials needed might turn into something like

- 2x XIAO-nRF52840
- 10 x 1.25A Blank Keycaps
- 50 x 1A Blank Keycaps
- (60 ± 2) x Gateron G Pro 3.0 (Red or Brown) Switches
- (60 ± 2) x Diodes (gotta choose one am not sure to use SMD or through-hole(THT
  ig))
- 4 x M3x16mm screws
- 4 x M3x5mx4mm heatset inserts
- 3d printed case (obviously)

Idk if i buy things ± 2 or more. as this is my second project i will probably
make so many mistakes. The above list is subjected to change as i don't know
what i will add/remove.

I initially wanted to design a fully custom PCB from scratch using the RP2040.
In my head it sounded like a “proper build.” But in reality, it’s not in my
league right now. I’m not trying to turn this into a failure.

So the new goal is to build something I can actually finish.

A keyboard that works first, and then gets refined.

Still, it feels like the good starting point. I’m not building the perfect
keyboard. I’m building my first real SplitKeeb. And its my second project using
PCB's and 3D printed case (last was obviously the hackpad) Also this is my first
time writing a journal so... The Journals might have some issues with usage of
English and other stuff.

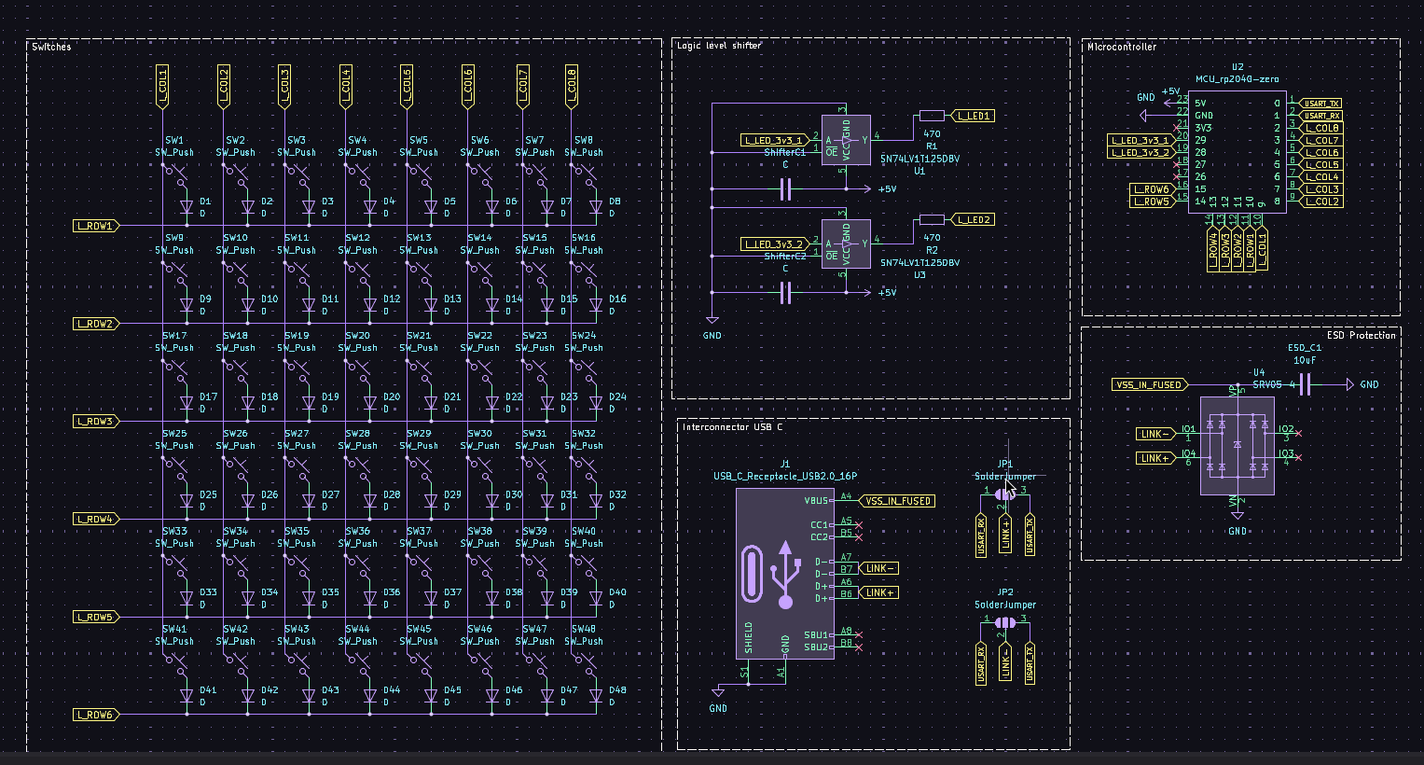
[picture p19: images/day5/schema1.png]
schema1
And i tried to figureout a simple schema for the board 
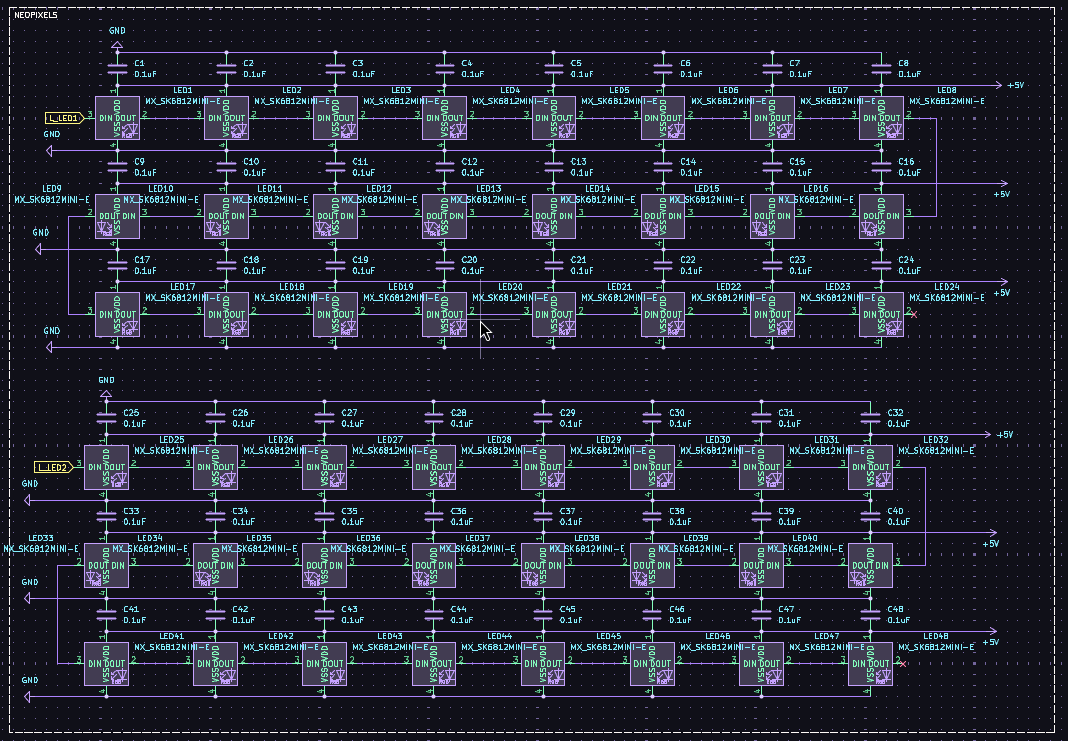
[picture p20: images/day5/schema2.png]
schema2


## Day 2: Planning again

Time: 9am - 11am I think my Day 1 plans are not enough Idk am overwhelmed with
the possibilities I need to figure out another micro controller to achieve a
better keyboard that I can Daily Drive.\
Controller will be Based on RP2040 probably Maybe i will build a custom micro
controller (dev board) using the
[Hackclub Tutorial](https://blueprint.hackclub.com/starter-projects/devboard)
and my own magic ig

Time: 1pm - 5pm At last i figured out that i will use RP2040-Zero
[Wiki](https://www.waveshare.com/wiki/RP2040-Zero)
[Datasheet](https://m.media-amazon.com/images/I/A1tLPy1hLqL.pdf)

And the keyboard layout will be
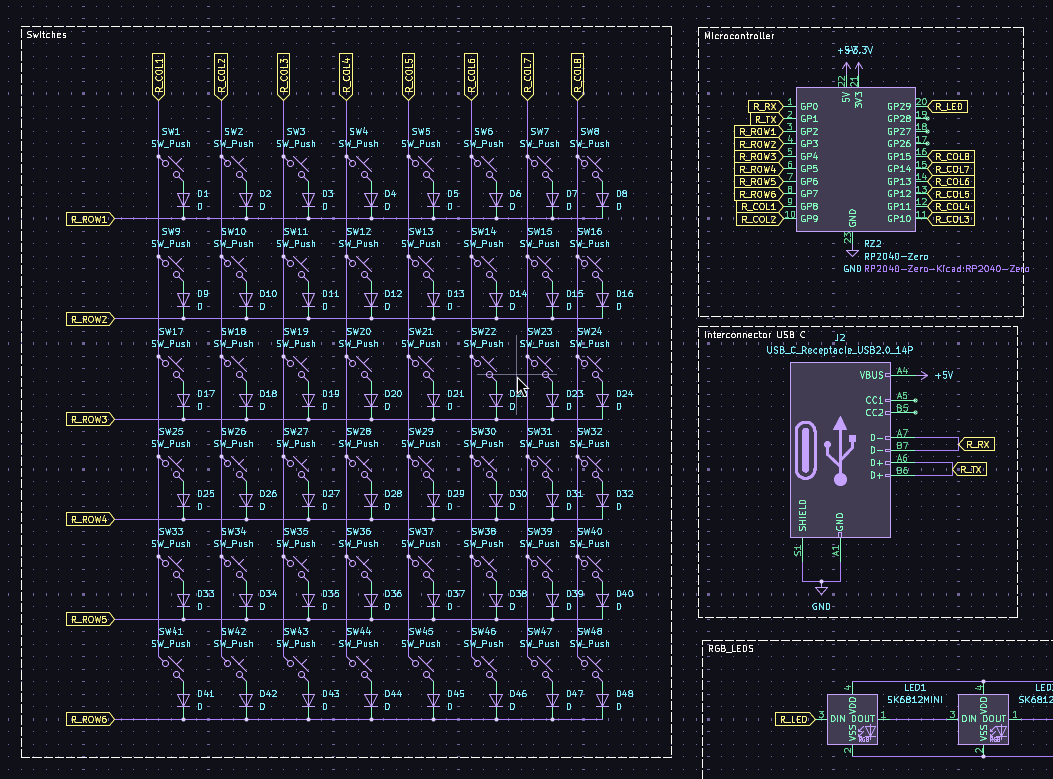
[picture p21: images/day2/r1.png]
r1


First i thought of using the TRRS Connection between the keyboards. Then i
realized that i can use USB C for the interconnection to use so that i can use
USB C to USB C cables.

PCB design is in progress and i expect it to finish by tomorrow.

Also for the case i will be checking out If i can use the PCB Layering (idk what
its called gotta check that) and the possibilities to build 2 pcb on top and
bottom of it

Time 6pm - 10:30pm Starting on PCB design. Finding out How i can interconnect
both sides via USB-C Spend a lot of time searching for USB-C and how to do the
schematics

The schematics will be
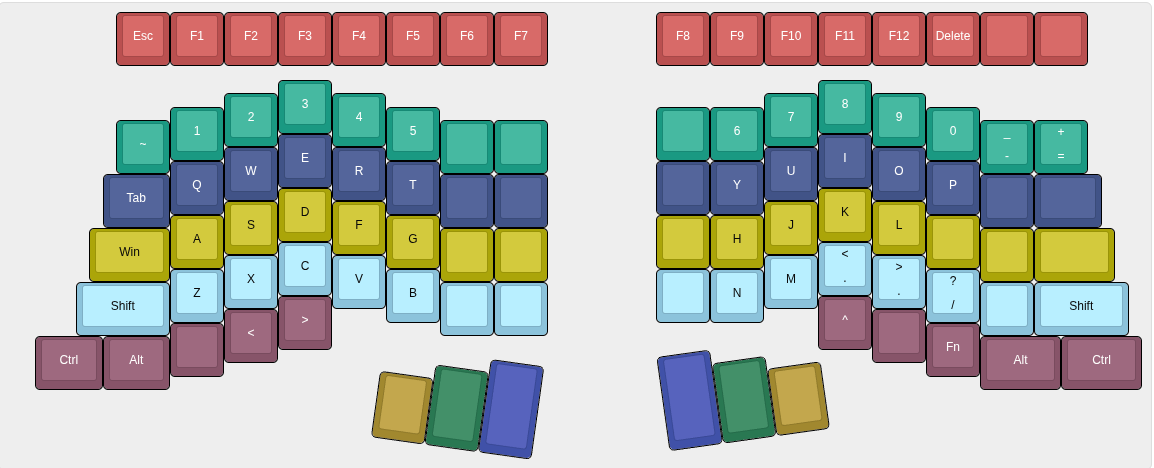
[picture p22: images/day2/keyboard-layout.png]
keyboard-layout

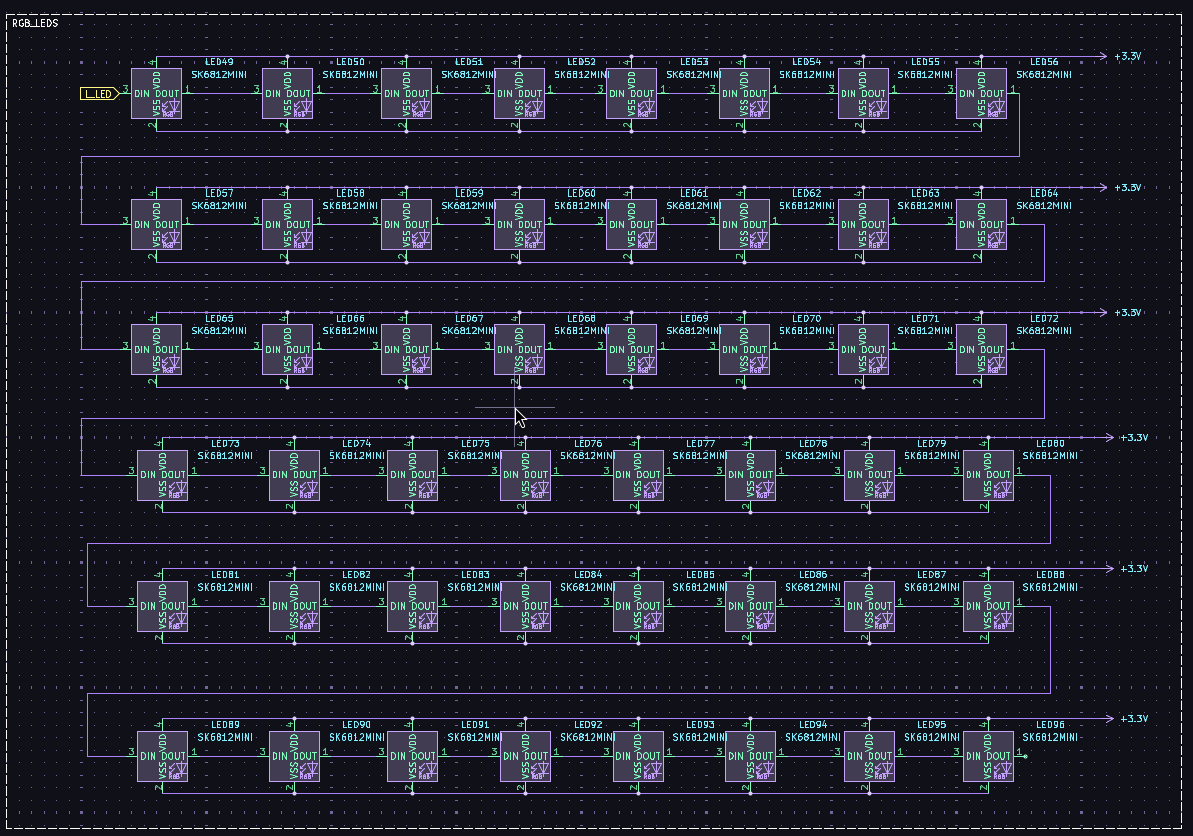
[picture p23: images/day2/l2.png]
l2

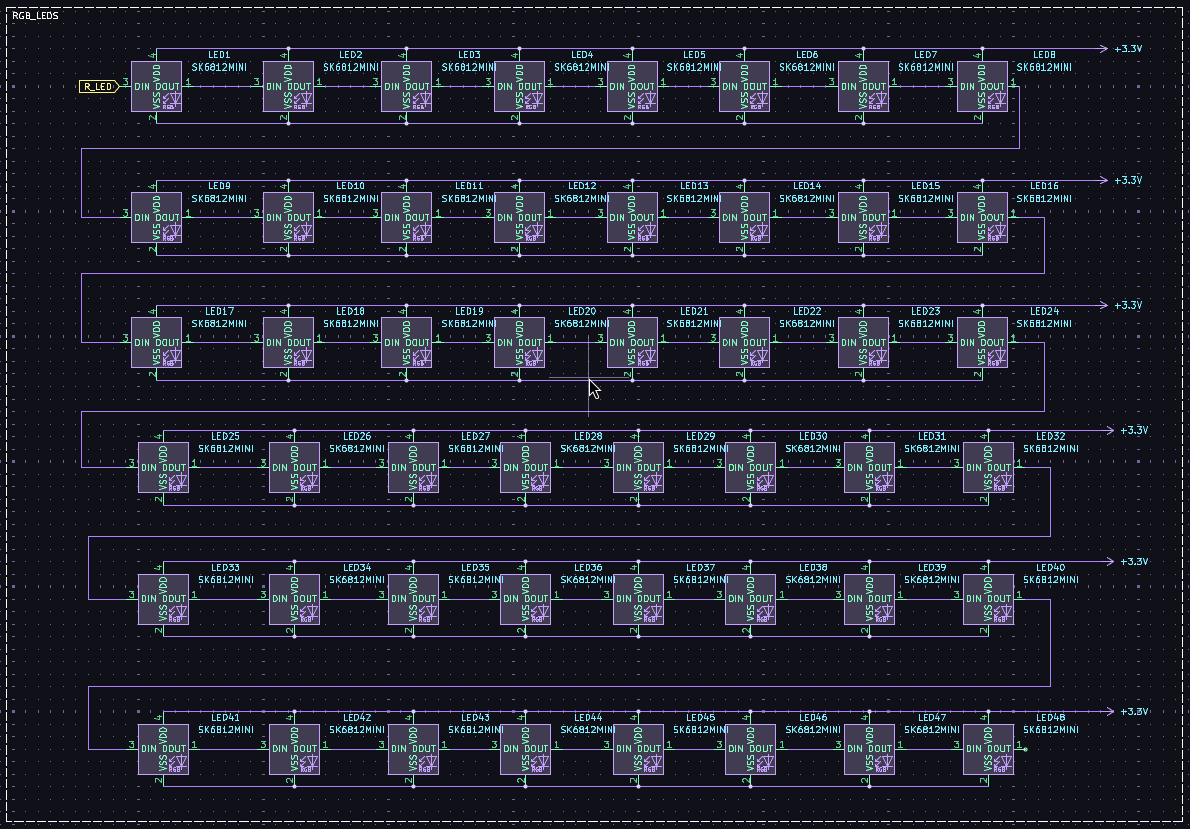
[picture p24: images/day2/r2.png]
r2

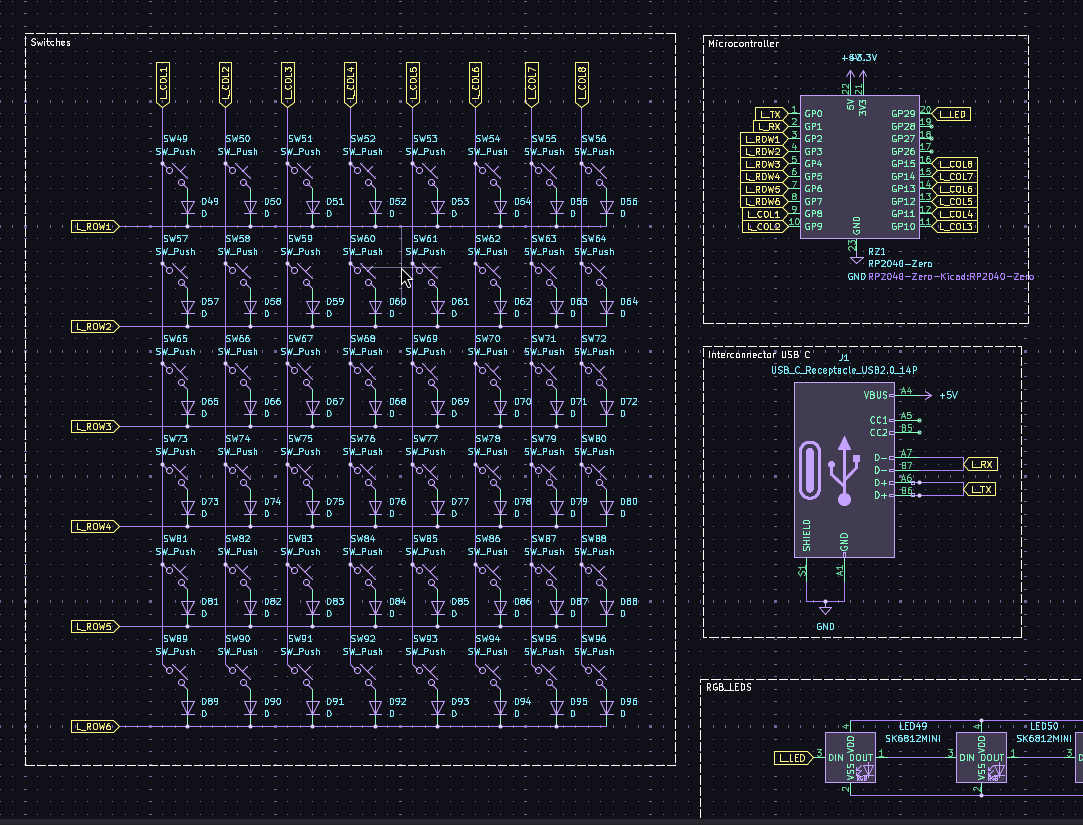
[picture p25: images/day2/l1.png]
l1


Found some useful articles and projects for inspiration
[ErgoDonk Zero](https://github.com/JellyTitan/ErgoDonk-Zero)
[Hardware design with RP2040](https://pip-assets.raspberrypi.com/categories/814-rp2040/documents/RP-008279-DS-1-hardware-design-with-rp2040.pdf)

Custom DIY Keyboard Design and Build: Schematic + PCB + Case | Part 1 - RP2040
by Robert Feranec: [Video](https://www.youtube.com/watch?v=N4cLFE0FF2U) |
[OSHWLab Link](https://oshwlab.com/robertferanec/custom-keyboard)

[How to Design Mechanical Keyboard PCBs with Kicad by Joe Scotto](https://www.youtube.com/watch?v=8WXpGTIbxlQ)

[How To: Split Keyboard with RP2040 and KMK](https://sanderg.nl/en/posts/how-to-split-keyboard-with-rp2040-and-kmk/)

## Day 3: Starting to work on PCB

#### KB Placer or No KB Placer ?

##### Time: 7-8:15am

I tried to use KB Placer to place my layout with my keyboard-layout.json by
[keyboard-layout-editor](https://www.keyboard-layout-editor.com/) But searching
through slack i found that some one got banned for using
[EroGen](https://github.com/adamws/kicad-kbplacer) and
[KB Placer](https://github.com/adamws/kicad-kbplacer), I don't need that fate to
my split keyboard. So am still waiting for the Slack Support to get me a Answer
to use or not use the plugin (i need it soooo bad to place the keys for my
keyboard, no routing or other fancy stuff)

[kbplacer image]

##### Time: 8:15am - 10:15am

I think i will do it without the KBPlacer ig, but it will take so much time than
using that. soooooo i need someone to help me to decide to use or not use
KBPlacer plugin for the layout.

Anyways am starting to do the PCB Layout by hand rn. to spend my time
efficiently

I started the pcb design and found out that the RP2040 symbols and footprints
where invalid when i referred the
[RP2040-Zero Wiki](https://www.waveshare.com/wiki/RP2040-Zero)

Then i found that i should use SK6812MINI-E Instead of SK6812MINI. Spend working
till 8pm. Now i hopefully found the repo with the footprints and symbols,
[marbastlib](https://github.com/ebastler/marbastlib) Am redoing the PCB again...

## Day 4: Working on schematics and improving it

I added my schematic for review in `#blueprint` in Hackclub Slack , `@sandgum`
helped me to figure out the logic level converter and some resistors i should
use

The pcb structure is ready. Added 0.1uF(100nF) Capacitors to the

## Day 5: Final schematics and pcb for left side.

I didn't time my things as am lazy, But the changes made are use 0.1uF
capacitors as recommended in the sk6812mini-e docs.

Added A ESD protection circuit inspired from YAMEK keyboards, fixed the
schematics and wireup the pcb the result looks like

## Day 6: ReImplementation ??

Updated the schematics to use a much better MCU, add a Battery, 2.4ghz
(interconnection and connection with a dongle if possible), BLE and a overall
better schematics.

I will hopefully finish the pcb by 2 days, i will start working on the 3d model
for the case tommorrow.






# Reference Links

## Display

- **Nice!View**\
  https://shop.beekeeb.com/products/nice-view-with-sockets-power-saving-display-for-wireless-split-keyboard

## MCU / Wireless

- **Holyiot 18010 module**\
  Datasheet: http://www.holyiot.com/tp/2019042516322180424.pdf\
  Robu.in: https://robu.in/product/holyiot-18010-nrf52840-chipset-ble-module/

## Switch Sockets

- **Gateron Hot-swap PCB Socket 2.0 (KS-2P02B01-01)**\
  Datasheet:
  https://gateron.com/u_file/2311/22/file/GATERONUpgradeHot-swapPCB20Socket-KS-2P02B01-01-a.pdf

## LEDs

- **SK6812MINI-E (addressable RGB LED)**\
  Datasheet:
  https://cdn-shop.adafruit.com/product-files/4960/4960_SK6812MINI-E_REV02_EN.pdf

## USB-C

- **USB Type-C receptacle (HRO TYPE-C-31-M-23, right-angle, 16P, SMD)**\
  Product page:
  https://robu.in/product/type-c-31-m-23-hroparts-1-surface-mount-right-angle-16p-female-55%e2%84%8385%e2%84%83-type-c-smd-usb-connectors-rohs/

## Debug / Tools

- **Raspberry Pi Debug Probe**\
  Documentation:
  https://www.raspberrypi.com/documentation/microcontrollers/debug-probe.html

## Logic / Level Shifting

- **SN74LV1T125DBV (single-channel level translator / buffer)**\
  Digi-Key:
  https://www.digikey.in/en/products/detail/texas-instruments/SN74LV1T125DBVR/4555571\
  Datasheet: https://www.ti.com/lit/ds/symlink/sn74lv1t125.pdf

## Battery Charging (idk i will probably change it soon)

- **BQ24090DGQ (Li-ion charger / power path)**\
  Digi-Key:
  https://www.digikey.in/en/products/detail/texas-instruments/BQ24090DGQT/2237296\
  Datasheet _(BQ24092 family doc)_:
  https://www.ti.com/lit/ds/symlink/bq24092.pdf

## Connectors

- **JST 2P 2.0mm**\
  AliExpress: https://www.aliexpress.com/item/1005006034725605.html

## ESD Protection

- **USBLC6-2SC6**\
  Digi-Key:
  https://www.digikey.in/en/products/detail/stmicroelectronics/USBLC6-2SC6/1040559\
  Datasheet: https://www.st.com/resource/en/datasheet/cd00050750.pdf

## Voltage Regulators

- **XC6206P332MR (3.3V LDO regulator)**\
  Digi-Key: https://www.digikey.in/en/products/detail/umw/XC6206P332MR/17635277\
  LCSC: https://www.lcsc.com/product-detail/C5252899.html

## Day 7: Complete Right side PCB and working on the case

Today i worked on the PCB and improved the schematics of the Keyboard,
Symmetrical design is not gonna happen, so i decided to do them separately.

I strugled with implementing BMS(Battery Management System) and the members from
Keyboard Atelier Helped me a lot reviewing my schematics, I will be uploading my
pcb for review there too, i think i will use sandwich case design

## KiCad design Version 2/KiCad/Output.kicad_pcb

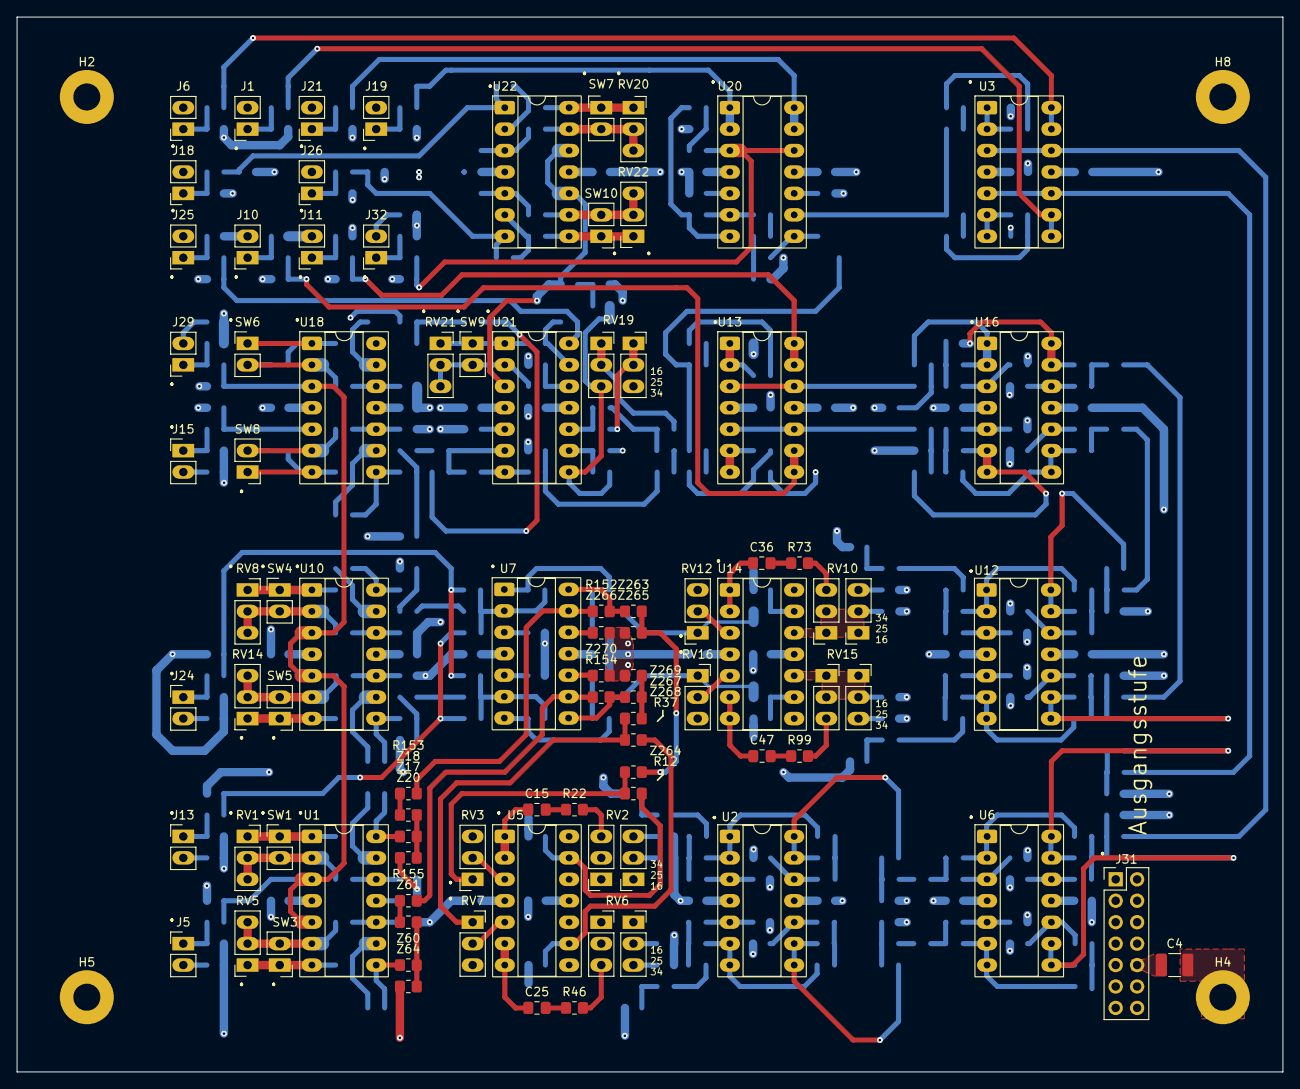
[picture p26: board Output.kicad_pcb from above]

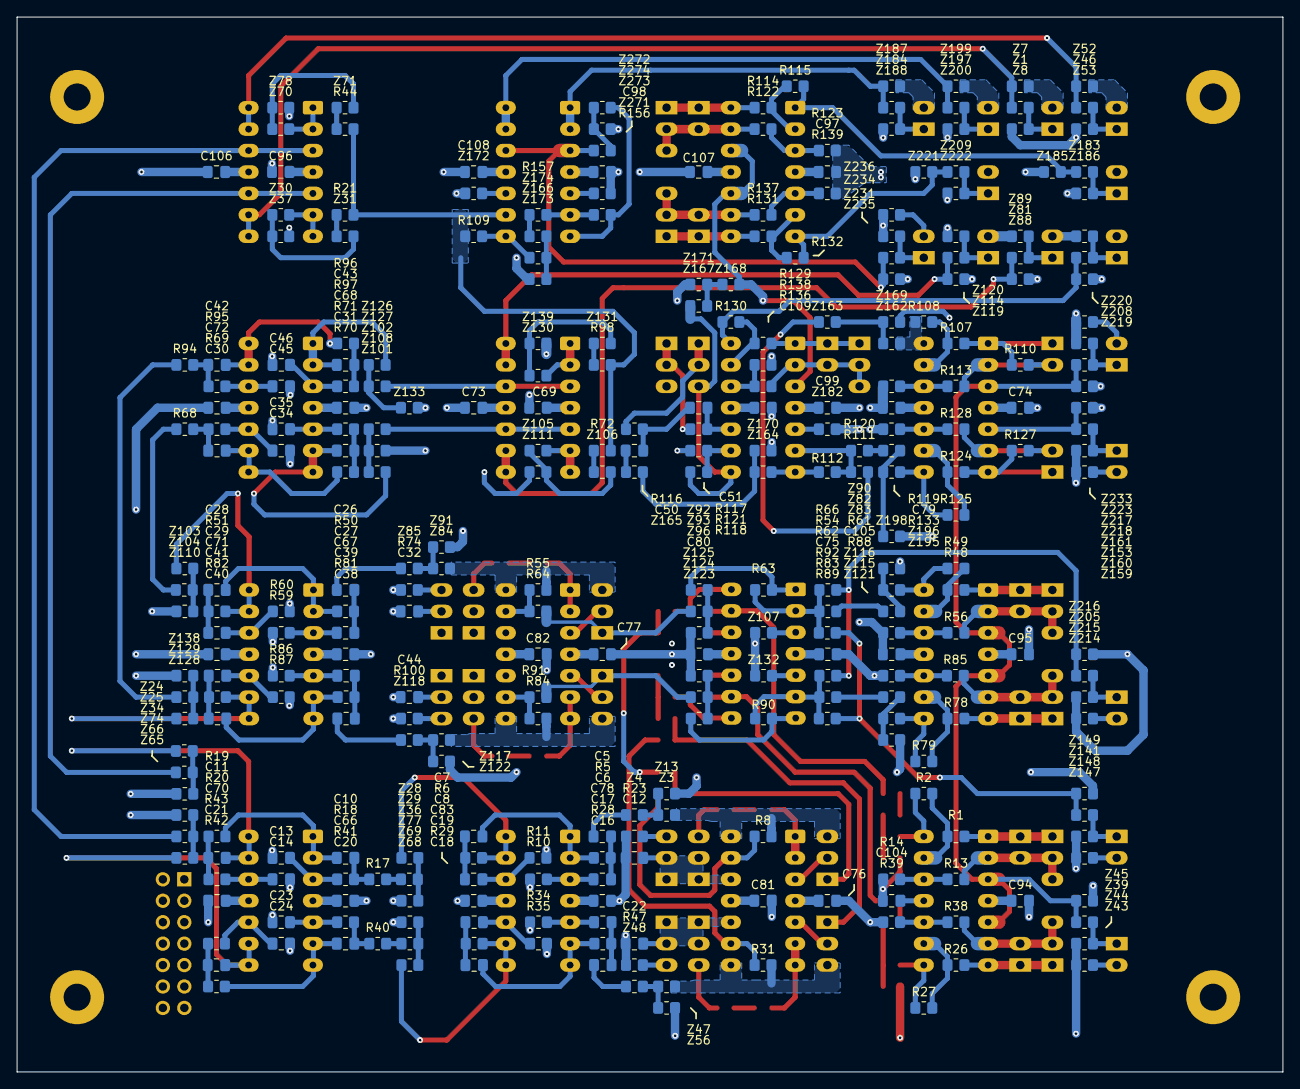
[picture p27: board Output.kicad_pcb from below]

Board: 4 copper layers, 150.0 x 125.0 mm, 393 parts (304 on the bottom side), 253 nets.

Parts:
C4: 10n; C_1210_3225Metric_Pad1.33x2.70mm_HandSolder
C5, C6, C7, C8, C10, C11, C13, C14, C16, C17, C18, C19, C20, C21, C23, C24, C26, C27, C28, C29, C30, C31, C34, C35, C38, C39, C40, C41, C42, C43, C45, C46: 130n; C_0805_2012Metric_Pad1.18x1.45mm_HandSolder
C12, C22, C32, C44: 470p; C_0805_2012Metric_Pad1.18x1.45mm_HandSolder
C15, C25, C36, C47: 3n; C_0805_2012Metric_Pad1.18x1.45mm_HandSolder
C50, C51: 6n8; C_0805_2012Metric_Pad1.18x1.45mm_HandSolder
C66, C67, C68, C69, C70, C71, C72, C73, C74, C75, C76, C77, C78, C79, C80, C81, C82, C83, C94, C95, C96, C97, C98, C99, C104, C105, C106, C107, C108, C109: 100n; C_0805_2012Metric_Pad1.18x1.45mm_HandSolder
H2, H5, H8: MountingHole; MountingHole_3.2mm_M3_Pad
H4: MountingHole_Pad; MountingHole_3.2mm_M3_Pad
J1: Bass_Out; PinSocket_1x02_P2.54mm_Vertical_LongPads
J5: Phono/Line_In; PinHeader_1x02_P2.54mm_Vertical_LongPads
J6: Kick_Out; PinSocket_1x02_P2.54mm_Vertical_LongPads
J10: Mid_Out; PinSocket_1x02_P2.54mm_Vertical_LongPads
J11: High_Out; PinSocket_1x02_P2.54mm_Vertical_LongPads
J13, J15, J24: Mic_Effekt_In; PinHeader_1x02_P2.54mm_Vertical_LongPads
J18: AUX_Send_1; PinSocket_1x02_P2.54mm_Vertical_LongPads
J19: Line_Out_L; PinSocket_1x02_P2.54mm_Vertical_LongPads
J21: Line_Out_R; PinSocket_1x02_P2.54mm_Vertical_LongPads
J25: AUX_Send_3; PinSocket_1x02_P2.54mm_Vertical_LongPads
J26: AUX_Send_2; PinSocket_1x02_P2.54mm_Vertical_LongPads
J29, J32: Pegel_Out; PinSocket_1x02_P2.54mm_Vertical_LongPads
J31: Conn_02x07_Odd_Even; PinHeader_2x07_P2.54mm_Vertical
R1, R26, R48, R78, R114, R129, R131: 4k7; R_0805_2012Metric_Pad1.20x1.40mm_HandSolder
R2, R21, R27, R44, R49, R54, R62, R63, R66, R72, R79, R83, R89, R90, R92, R98, R107, R108, R109, R111, R112, R115, R116, R117, R118, R120, R121, R124, R125, R130, R132, R152, R153, R154, R155, R156, R157: 10k; R_0805_2012Metric_Pad1.20x1.40mm_HandSolder
R5, R6, R10, R11, R22, R23, R28, R29, R34, R35, R46, R47, R50, R51, R59, R60, R73, R74, R81, R82, R86, R87, R99, R100: 6k8; R_0805_2012Metric_Pad1.20x1.40mm_HandSolder
R8, R12, R17, R18, R19, R20, R31, R37, R40, R41, R42, R43, R55, R64, R68, R69, R70, R71, R84, R91, R94, R95, R96, R97: 22k; R_0805_2012Metric_Pad1.20x1.40mm_HandSolder
R13, R38, R56, R85, R122, R136, R137: 470R; R_0805_2012Metric_Pad1.20x1.40mm_HandSolder
R14, R39, R61, R88, R123, R138, R139: 1k; R_0805_2012Metric_Pad1.20x1.40mm_HandSolder
R110, R113, R119, R127, R128, R133: 5k; R_0805_2012Metric_Pad1.20x1.40mm_HandSolder
RV1, RV5, RV8, RV14, RV20, RV21, RV22: 50k log; PinSocket_1x03_P2.54mm_Vertical_LongPads
RV2, RV10: 220k log; PinSocket_2x03_P2.54mm_Vertical_LongPads_Mirrored
RV3, RV7, RV12, RV16: 47k lin; PinSocket_1x03_P2.54mm_Vertical_LongPads
RV6, RV15, RV19: 220k log; PinSocket_2x03_P2.54mm_Vertical_LongPads
SW1, SW3, SW4, SW5, SW6, SW7, SW8, SW9, SW10: SW_SPDT; PinHeader_1x02_P2.54mm_Vertical_LongPads
U1, U2, U3, U5, U6, U7, U10, U12, U13, U14, U16, U18, U20, U21, U22: TL074; DIP-14_W7.62mm_Socket_LongPads
Z1, Z3, Z4, Z7, Z8, Z13, Z17, Z18, Z20, Z24, Z25, Z28, Z29, Z30, Z31, Z34, Z36, Z37, Z39, Z43, Z44, Z45, Z46, Z47, Z48, Z52, Z53, Z56, Z60, Z61, Z64, Z65, Z66, Z68, Z69, Z70, Z71, Z74, Z77, Z78, Z81, Z82, Z83, Z84, Z85, Z88, Z89, Z90, Z91, Z92, Z93, Z96, Z101, Z102, Z103, Z104, Z105, Z106, Z107, Z108, Z110, Z111, Z114, Z115, Z116, Z117, Z118, Z119, Z120, Z121, Z122, Z123, Z124, Z125, Z126, Z127, Z128, Z129, Z130, Z131, Z132, Z133, Z138, Z139, Z141, Z147, Z148, Z149, Z153, Z159, Z160, Z161, Z162, Z163, Z164, Z165, Z166, Z167, Z168, Z169, Z170, Z171, Z172, Z173, Z174, Z182, Z183, Z184, Z185, Z186, Z187, Z188, Z195, Z196, Z197, Z198, Z199, Z200, Z205, Z208, Z209, Z214, Z215, Z216, Z217, Z218, Z219, Z220, Z221, Z222, Z223, Z231, Z233, Z234, Z235, Z236, Z263, Z264, Z265, Z266, Z267, Z268, Z269, Z270, Z271, Z272, Z273, Z274: R_0805_2012Metric_Pad1.20x1.40mm_HandSolder

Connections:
9V_GND_O: J31.1, J31.2, J31.3, J31.4
+9V_O: J31.5, J31.6
+15V_O: C66.2, C67.2, C68.2, C69.2, C74.2, C75.2, C76.2, C77.2, C78.2, C94.2, C95.2, C96.2, C97.2, C98.2, C99.2, J31.13, J31.14, U1.4 (V+), U2.4 (V+), U3.4 (V+), U5.4 (V+), U6.4 (V+), U7.4 (V+), U10.4 (V+), U12.4 (V+), U13.4 (V+), U14.4 (V+), U16.4 (V+), U18.4 (V+), U20.4 (V+), U21.4 (V+), U22.4 (V+)
-15V_O: C70.2, C71.2, C72.2, C73.2, C79.2, C80.2, C81.2, C82.2, C83.2, C104.2, C105.2, C106.2, C107.2, C108.2, C109.2, J31.7, J31.8, U1.11 (V-), U2.11 (V-), U3.11 (V-), U5.11 (V-), U6.11 (V-), U7.11 (V-), U10.11 (V-), U12.11 (V-), U13.11 (V-), U14.11 (V-), U16.11 (V-), U18.11 (V-), U20.11 (V-), U21.11 (V-), U22.11 (V-)
GND_O: C4.2, C12.2, C13.1, C14.1, C22.2, C23.1, C24.1, C32.2, C34.1, C35.1, C44.2, C45.1, C46.1, C66.1, C67.1, C68.1, C69.1, C70.1, C71.1, C72.1, C73.1, C74.1, C75.1, C76.1, C77.1, C78.1, C79.1, C80.1, C81.1, C82.1, C83.1, C94.1, C95.1, C96.1, C97.1, C98.1, C99.1, C104.1, C105.1, C106.1, C107.1, C108.1, C109.1, J1.2, J6.2, J10.2, J11.2, J18.2, J19.2, J21.2, J25.2, J26.2, J31.9, J31.10, J31.11, J31.12, R10.1, R11.1, R14.1, R23.1, R34.1, R35.1, R39.1, R47.1, R59.1, R60.1, R61.1, R74.1, R86.1, R87.1, R88.1, R100.1, R119.2, R121.2, R123.2, R133.2, R138.2, R139.2, RV19.4, Z7.2, Z8.2, Z13.2, Z20.2, Z34.2, Z36.2, Z37.2, Z43.2, Z44.2, Z45.2, Z52.2, Z53.2, Z56.2, Z64.2, Z74.2, Z77.2, Z78.2, Z88.2, Z89.2, Z90.2, Z91.2, Z96.2, Z107.2, Z108.2, Z110.2, Z111.2, Z119.2, Z120.2, Z121.2, Z122.2, Z125.2, Z132.2, Z133.2, Z138.2, Z139.2, Z147.2, Z148.2, Z149.2, Z159.2, Z160.2, Z161.2, Z169.2, Z170.2, Z171.2, Z172.2, Z173.2, Z182.2, Z185.2, Z186.2, Z187.2, Z188.2, Z198.2, Z199.2, Z200.2, Z214.2, Z215.2, Z216.2, Z218.2, Z219.2, Z220.2, Z221.2, Z222.2, Z223.2, Z233.2, Z234.2, Z235.2, Z236.2, Z265.2, Z266.2, Z269.2, Z270.2, Z271.2, Z274.2
unnamed: C4.1, H4.1
unnamed: C5.1, Z4.2
unnamed: C5.2, C6.1, R5.1
unnamed: C7.2, C8.1, R6.1
unnamed: C10.1, R17.2, R18.1
unnamed: C11.1, R19.2, R20.1
unnamed: C15.1, R22.1
unnamed: C16.1, Z48.2
unnamed: C16.2, C17.1, R28.1
unnamed: C18.2, C19.1, R29.1
unnamed: C20.1, R40.2, R41.1
unnamed: C21.1, R42.2, R43.1
unnamed: C25.1, R46.1
unnamed: C26.1, Z85.2
unnamed: C26.2, C27.1, R50.1
unnamed: C28.2, C29.1, R51.1
unnamed: C30.1, R68.2, R69.1
unnamed: C31.1, R70.2, R71.1
unnamed: C36.1, R73.1
unnamed: C38.1, Z118.2
unnamed: C38.2, C39.1, R81.1
unnamed: C40.2, C41.1, R82.1
unnamed: C42.1, R94.2, R95.1
unnamed: C43.1, R96.2, R97.1
unnamed: C47.1, R99.1
unnamed: C50.1, C51.2, R116.1
unnamed: C50.2, Z165.2
unnamed: J1.1, Z1.2, Z8.1
unnamed: J5.1, Z39.1, Z44.1
unnamed: J5.2, Z43.1
unnamed: J6.1, Z46.2, Z53.1
unnamed: J10.1, Z81.2, Z89.1
unnamed: J11.1, Z114.2, Z120.1
unnamed: J13.1, Z141.1, Z148.1
unnamed: J13.2, Z147.1
unnamed: J15.1, Z153.1, Z160.1
unnamed: J15.2, Z159.1
unnamed: J18.1, Z183.2, Z186.1
unnamed: J19.1, Z184.2, Z188.1
unnamed: J21.1, Z197.2, Z200.1
unnamed: J24.1, Z205.1, Z215.1
unnamed: J24.2, Z214.1
unnamed: J25.1, Z208.2, Z220.1
unnamed: J26.1, Z209.2, Z222.1
unnamed: J29.1, Z217.2, Z223.1
unnamed: J29.2, Z233.1
unnamed: J32.1, Z231.1, Z234.1
unnamed: J32.2, Z236.1
unnamed: R2.2, U1.14, Z17.1
unnamed: R8.2, RV3.3, U5.14, Z3.1
unnamed: R12.1, RV3.1, Z264.2
unnamed: R17.1, Z29.2
unnamed: R21.1, Z31.2
unnamed: R22.2, RV2.3
unnamed: R23.2, RV2.4
unnamed: R27.2, U1.8, Z60.1
unnamed: R31.2, RV7.3, U5.8, Z47.1
unnamed: R37.1, RV7.1, Z268.2
unnamed: R40.1, Z69.2
unnamed: R44.1, Z71.2
unnamed: R46.2, RV6.3
unnamed: R47.2, RV6.4
unnamed: R49.2, U10.14, Z82.1
unnamed: R54.1, Z83.2
unnamed: R55.2, RV12.3, U14.14, Z84.1
unnamed: R62.1, R89.1, Z141.2, Z149.1
unnamed: R63.2, U7.1, Z92.1
unnamed: R64.1, RV12.1, Z93.2
unnamed: R66.1, R92.1, Z205.2, Z216.1
unnamed: R68.1, Z104.2
unnamed: R72.1, Z106.2
unnamed: R73.2, RV10.3
unnamed: R74.2, RV10.4
unnamed: R79.2, U10.8, Z115.1
unnamed: R83.1, Z116.2
unnamed: R84.2, RV16.3, U14.8, Z117.1
unnamed: R90.2, U7.7, Z123.1
unnamed: R91.1, RV16.1, Z124.2
unnamed: R94.1, Z129.2
unnamed: R98.1, Z131.2
unnamed: R99.2, RV15.3
unnamed: R100.2, RV15.4
unnamed: R108.1, U18.14, Z162.1
unnamed: R109.2, U20.8, Z166.1
unnamed: R111.2, Z163.2
unnamed: R112.1, U21.7, Z164.1
unnamed: R115.1, U22.1, Z183.1, Z185.1
unnamed: R116.2, RV19.1, RV19.2
unnamed: R117.2, RV19.5, RV19.6
unnamed: R118.1, RV19.3, U21.8, Z167.1
unnamed: R120.2, Z196.2
unnamed: R125.1, U18.8, Z195.1
unnamed: R130.1, U21.14, Z208.1, Z219.1
unnamed: R132.1, U22.7, Z209.1, Z221.1
unnamed: R152.2, U7.14, Z263.1
unnamed: R153.1, Z18.2
unnamed: R154.2, U7.8, Z267.1
unnamed: R155.1, Z61.2
unnamed: R156.1, U20.7, Z272.1
unnamed: R157.1, Z174.2
unnamed: R1.1, RV1.1, SW1.1 (A), U1.1
unnamed: R13.1, RV1.2, RV1.3, SW1.2 (B), U1.2 (-)
unnamed: R26.1, RV5.1, SW3.1 (A), U1.7
unnamed: R38.1, RV5.2, RV5.3, SW3.2 (B), U1.6 (-)
unnamed: R48.1, RV8.1, SW4.1 (A), U10.1
unnamed: R56.1, RV8.2, RV8.3, SW4.2 (B), U10.2 (-)
unnamed: R78.1, RV14.1, SW5.1 (A), U10.7
unnamed: R85.1, RV14.2, RV14.3, SW5.2 (B), U10.6 (-)
unnamed: R107.2, R110.1, SW6.1 (A), U18.1
unnamed: R110.2, R113.2, SW6.2 (B), U18.2 (-)
unnamed: R114.2, RV20.1, SW7.1 (A), U22.14
unnamed: R122.2, RV20.2, RV20.3, SW7.2 (B), U22.13 (-)
unnamed: R124.2, R127.1, SW8.1 (A), U18.7
unnamed: R127.2, R128.2, SW8.2 (B), U18.6 (-)
unnamed: R129.2, RV21.1, SW9.1 (A), U21.1
unnamed: R136.2, RV21.2, RV21.3, SW9.2 (B), U21.2 (-)
unnamed: R131.2, RV22.1, SW10.1 (A), U22.8
unnamed: R137.2, RV22.2, RV22.3, SW10.2 (B), U22.9 (-)
unnamed: R38.2, R39.2, U1.10 (+)
unnamed: R26.2, R27.1, U1.9 (-)
unnamed: R13.2, R14.2, U1.12 (+)
unnamed: R1.2, R2.1, U1.13 (-)
unnamed: C6.2, R10.2, U2.3 (+)
unnamed: C7.1, R5.2, U2.1, U2.2 (-)
unnamed: C17.2, R34.2, U2.5 (+)
unnamed: C18.1, R28.2, U2.6 (-), U2.7
unnamed: C19.2, R35.2, U2.10 (+)
unnamed: R29.2, U2.8, U2.9 (-), Z68.1
unnamed: C8.2, R11.2, U2.12 (+)
unnamed: R6.2, U2.13 (-), U2.14, Z28.1
unnamed: U3.3 (+), U3.12 (+), Z66.2
unnamed: U3.1, U3.2 (-), Z70.1
unnamed: U3.5 (+), U3.10 (+), Z25.2
unnamed: U3.6 (-), U3.7, Z30.1
unnamed: U3.8, U3.9 (-), Z1.1, Z7.1
unnamed: U3.13 (-), U3.14, Z46.1, Z52.1
unnamed: RV3.2, U5.3 (+)
unnamed: C15.2, U5.1, U5.2 (-)
unnamed: RV7.2, U5.5 (+)
unnamed: C25.2, U5.6 (-), U5.7
unnamed: C22.1, RV6.1, RV6.2, RV6.5, RV6.6, U5.10 (+)
unnamed: R31.1, R37.2, U5.9 (-)
unnamed: C12.1, RV2.1, RV2.2, RV2.5, RV2.6, U5.12 (+)
unnamed: R8.1, R12.2, U5.13 (-)
unnamed: C13.2, R18.2, U6.3 (+)
unnamed: C10.2, R19.1, U6.1, U6.2 (-)
unnamed: C23.2, R41.2, U6.5 (+)
unnamed: C20.2, R42.1, U6.6 (-), U6.7
unnamed: C24.2, R43.2, U6.10 (+)
unnamed: C21.2, U6.8, U6.9 (-), Z65.1
unnamed: C14.2, R20.2, U6.12 (+)
unnamed: C11.2, U6.13 (-), U6.14, Z24.1
unnamed: U7.3 (+), Z107.1
unnamed: R54.2, R62.2, R63.1, R66.2, U7.2 (-)
unnamed: U7.5 (+), Z132.1
unnamed: R83.2, R89.2, R90.1, R92.2, U7.6 (-)
unnamed: U7.10 (+), Z270.1
unnamed: R154.1, R155.2, U7.9 (-)
unnamed: U7.12 (+), Z266.1
unnamed: R152.1, R153.2, U7.13 (-)
unnamed: U1.3 (+), U1.5 (+), U10.3 (+), U10.5 (+), U18.3 (+), Z39.2, Z45.1, Z217.1, Z218.1
unnamed: R85.2, R88.2, U10.10 (+)
unnamed: R78.2, R79.1, U10.9 (-)
unnamed: R56.2, R61.2, U10.12 (+)
unnamed: R48.2, R49.1, U10.13 (-)
unnamed: C27.2, R59.2, U12.3 (+)
unnamed: C28.1, R50.2, U12.1, U12.2 (-)
unnamed: C39.2, R86.2, U12.5 (+)
unnamed: C40.1, R81.2, U12.6 (-), U12.7
unnamed: C41.2, R87.2, U12.10 (+)
unnamed: R82.2, U12.8, U12.9 (-), Z128.1
unnamed: C29.2, R60.2, U12.12 (+)
unnamed: R51.2, U12.13 (-), U12.14, Z103.1
unnamed: U13.3 (+), U13.12 (+), Z127.2
unnamed: U13.1, U13.2 (-), Z130.1
unnamed: U13.5 (+), U13.10 (+), Z102.2
unnamed: U13.6 (-), U13.7, Z105.1
unnamed: U13.8, U13.9 (-), Z81.1, Z88.1
unnamed: U13.13 (-), U13.14, Z114.1, Z119.1
unnamed: RV12.2, U14.3 (+)
unnamed: C36.2, U14.1, U14.2 (-)
unnamed: RV16.2, U14.5 (+)
unnamed: C47.2, U14.6 (-), U14.7
unnamed: C44.1, RV15.1, RV15.2, RV15.5, RV15.6, U14.10 (+)
unnamed: R84.1, R91.2, U14.9 (-)
unnamed: C32.1, RV10.1, RV10.2, RV10.5, RV10.6, U14.12 (+)
unnamed: R55.1, R64.2, U14.13 (-)
unnamed: C46.2, R97.2, U16.3 (+)
unnamed: C43.2, U16.1, U16.2 (-), Z126.1
unnamed: C35.2, R71.2, U16.5 (+)
unnamed: C31.2, U16.6 (-), U16.7, Z101.1
unnamed: C34.2, R69.2, U16.10 (+)
unnamed: C30.2, R70.1, U16.8, U16.9 (-)
unnamed: C45.2, R95.2, U16.12 (+)
unnamed: C42.2, R96.1, U16.13 (-), U16.14
unnamed: U18.5 (+), Z153.2, Z161.1
unnamed: R128.1, R133.1, U18.10 (+)
unnamed: R124.1, R125.2, U18.9 (-)
unnamed: R113.1, R119.1, U18.12 (+)
unnamed: R107.1, R108.2, U18.13 (-)
unnamed: U20.3 (+), U20.12 (+), Z231.2, Z235.1, Z273.2
unnamed: U20.1, U20.2 (-), Z184.1, Z187.1
unnamed: U20.5 (+), Z271.1
unnamed: R156.2, R157.2, U20.6 (-)
unnamed: U20.10 (+), Z172.1
unnamed: R21.2, R44.2, R72.2, R98.2, R109.1, U20.9 (-)
unnamed: U20.13 (-), U20.14, Z197.1, Z199.1
unnamed: U21.3 (+), U22.10 (+), U22.12 (+), Z168.2
unnamed: U21.5 (+), Z182.1
unnamed: R111.1, R112.2, R120.1, U21.6 (-)
unnamed: C51.1, R117.1, U21.10 (+)
unnamed: R118.2, R121.1, U21.9 (-)
unnamed: R136.1, R138.1, U21.12 (+)
unnamed: R129.1, R130.2, U21.13 (-)
unnamed: R122.1, R123.1, U22.3 (+)
unnamed: R114.1, R115.2, U22.2 (-)
unnamed: R137.1, R139.1, U22.5 (+)
unnamed: R131.1, R132.2, U22.6 (-)
unnamed: Z3.2, Z4.1, Z13.1
unnamed: Z17.2, Z18.1, Z20.1
unnamed: Z24.2, Z25.1, Z34.1
unnamed: Z28.2, Z29.1, Z36.1
unnamed: Z30.2, Z31.1, Z37.1
unnamed: Z47.2, Z48.1, Z56.1
unnamed: Z60.2, Z61.1, Z64.1
unnamed: Z65.2, Z66.1, Z74.1
unnamed: Z68.2, Z69.1, Z77.1
unnamed: Z70.2, Z71.1, Z78.1
unnamed: Z82.2, Z83.1, Z90.1
unnamed: Z84.2, Z85.1, Z91.1
unnamed: Z92.2, Z93.1, Z96.1
unnamed: Z101.2, Z102.1, Z108.1
unnamed: Z103.2, Z104.1, Z110.1
unnamed: Z105.2, Z106.1, Z111.1
unnamed: Z115.2, Z116.1, Z121.1
unnamed: Z117.2, Z118.1, Z122.1
unnamed: Z123.2, Z124.1, Z125.1
unnamed: Z126.2, Z127.1, Z133.1
unnamed: Z128.2, Z129.1, Z138.1
unnamed: Z130.2, Z131.1, Z139.1
unnamed: Z162.2, Z163.1, Z169.1
unnamed: Z164.2, Z165.1, Z170.1
unnamed: Z166.2, Z173.1, Z174.1
unnamed: Z167.2, Z168.1, Z171.1
unnamed: Z195.2, Z196.1, Z198.1
unnamed: Z263.2, Z264.1, Z265.1
unnamed: Z267.2, Z268.1, Z269.1
unnamed: Z272.2, Z273.1, Z274.1

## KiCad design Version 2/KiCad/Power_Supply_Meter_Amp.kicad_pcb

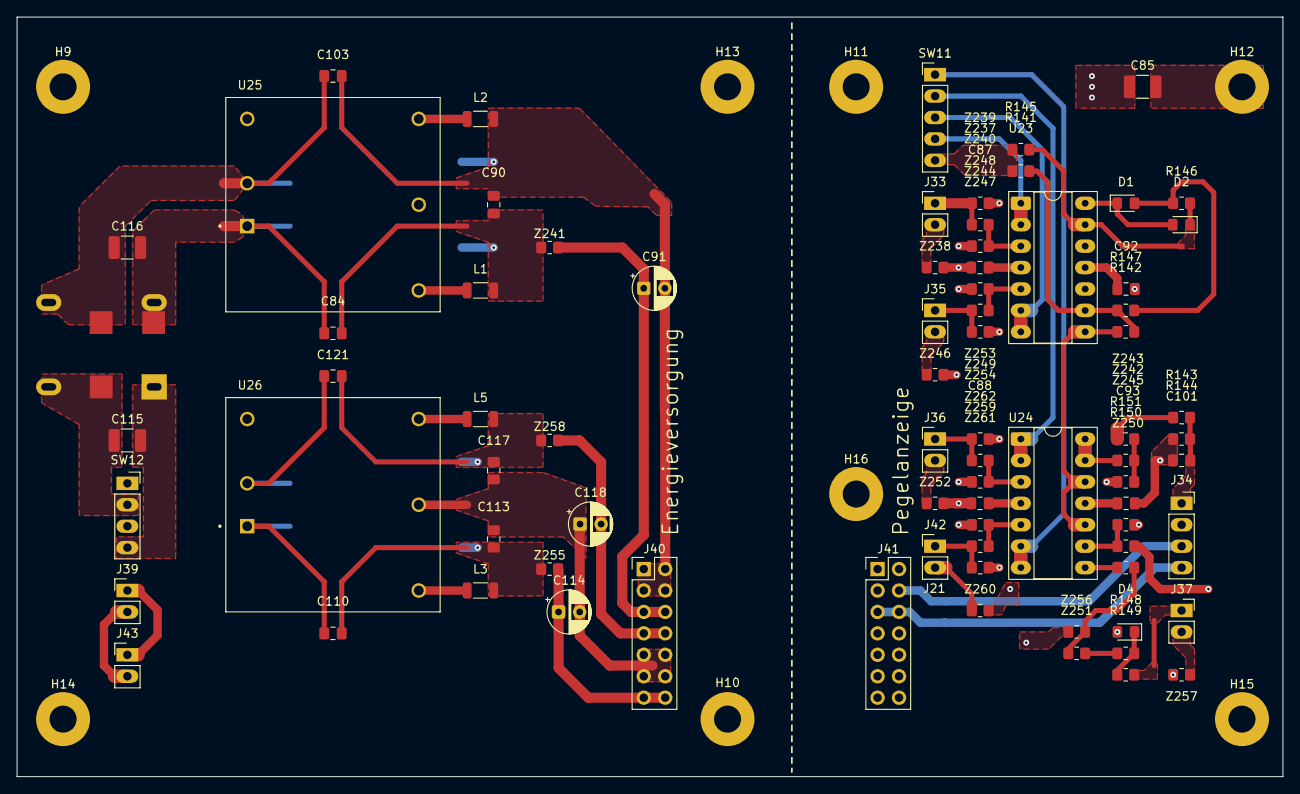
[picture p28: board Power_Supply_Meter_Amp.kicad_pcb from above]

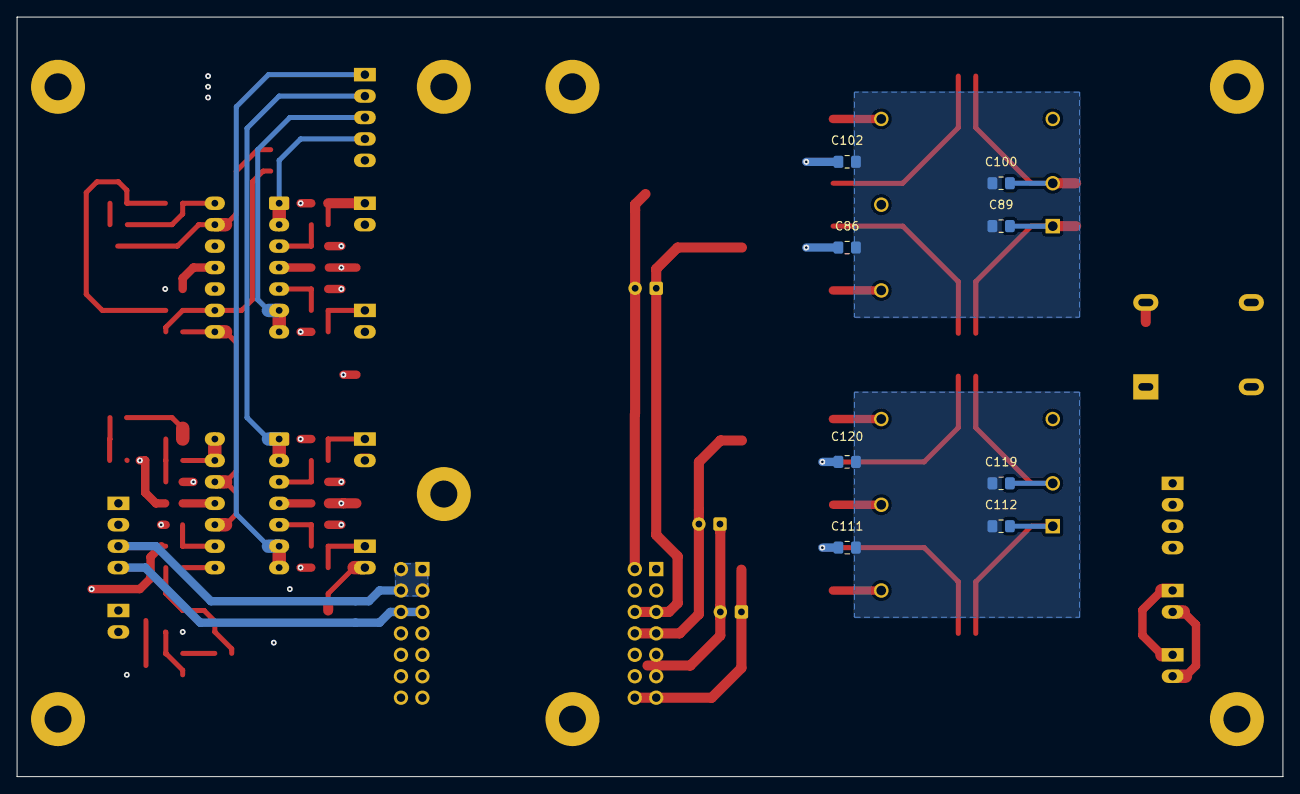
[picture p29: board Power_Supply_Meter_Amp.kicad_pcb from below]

Board: 4 copper layers, 150.0 x 90.0 mm, 95 parts (8 on the bottom side), 59 nets.

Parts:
C84, C103, C110, C121: 470p; C_0805_2012Metric_Pad1.18x1.45mm_HandSolder
C85: 10n; C_1210_3225Metric_Pad1.33x2.70mm_HandSolder
C86, C102, C111, C120: 1n; C_0805_2012Metric_Pad1.18x1.45mm_HandSolder
C87, C88, C90, C92, C93, C113, C117: 100n; C_0805_2012Metric_Pad1.18x1.45mm_HandSolder
C89, C100, C112, C119: 10n; C_0805_2012Metric_Pad1.18x1.45mm_HandSolder
C91, C114, C118: 10u; CP_Radial_D5.0mm_P2.50mm
C101: 4u7; C_0805_2012Metric_Pad1.18x1.45mm_HandSolder
C115, C116: 10u; C_1210_3225Metric_Pad1.33x2.70mm_HandSolder
D1, D2, D4: D; D_0805_2012Metric_Pad1.15x1.40mm_HandSolder
H9, H10, H11, H13, H14, H15, H16: MountingHole; MountingHole_3.2mm_M3_Pad
H12: MountingHole_Pad; MountingHole_3.2mm_M3_Pad
J33, J35, J36, J42: Pegel_In; PinHeader_1x02_P2.54mm_Vertical_LongPads
J34: VU_Meter_Out; PinSocket_1x04_P2.54mm_Vertical_LongPdas
J37: LED_Out; PinSocket_1x02_P2.54mm_Vertical_LongPads
J39: VCC_IN; PinHeader_1x02_P2.54mm_Vertical_LongPads
J40, J41: Conn_02x07_Odd_Even; PinHeader_2x07_P2.54mm_Vertical
J43: VCC_OUT; PinHeader_1x02_P2.54mm_Vertical_LongPads
L1, L2, L3, L5: Dämpfungsperle, 220 Ohm @ 100MHz, 0.5A; L_1206_3216Metric
L4: WE-SL575
R141: 20k; R_0805_2012Metric_Pad1.20x1.40mm_HandSolder
R142: 80k; R_0805_2012Metric_Pad1.20x1.40mm_HandSolder
R143, R144: 1k8; R_0805_2012Metric_Pad1.20x1.40mm_HandSolder
R145, R146, R149: 1k; R_0805_2012Metric_Pad1.20x1.40mm_HandSolder
R147, R148: 10k; R_0805_2012Metric_Pad1.20x1.40mm_HandSolder
R150: 12k; R_0805_2012Metric_Pad1.20x1.40mm_HandSolder
R151: 3k; R_0805_2012Metric_Pad1.20x1.40mm_HandSolder
SW11: SW_Rotary_1x4; PinHeader_1x05_P2.54mm_Vertical_LongPads
SW12: SW_DPST; PinSocket_1x04_P2.54mm_Vertical_LongPdas
U23, U24: TL074; DIP-14_W7.62mm_Socket_LongPads
U25: REC10K-2409; CONV_REC10K-2409SAW_H2
U26: REC10K-2415; CONV_REC10K-2415DAW_H2
Z237, Z238, Z239, Z240, Z241, Z242, Z243, Z244, Z245, Z246, Z247, Z248, Z249, Z250, Z251, Z252, Z253, Z254, Z255, Z256, Z257, Z258, Z259, Z260, Z261, Z262: R_0805_2012Metric_Pad1.20x1.40mm_HandSolder

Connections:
9V_GND_M: J34.3, J41.1, J41.2, J41.3, J41.4
9V_GND_P: C90.2, C91.2, C102.1, C103.2, J40.1, J40.2, J40.3, J40.4, L2.2
+9V_M: J34.4, J41.5, J41.6
+9V_P: C91.1, J40.5, J40.6, Z241.2
+15V_M: C87.2, C88.2, J41.13, J41.14, R150.1, U23.4 (V+), U24.4 (V+)
+15V_P: C114.1, J40.13, J40.14, Z255.2
-15V_M: C92.2, C93.2, J41.7, J41.8, U23.11 (V-), U24.11 (V-)
-15V_P: C118.2, J40.7, J40.8, Z258.2
/Pegel_Aux_Return: SW11.2, U24.1, U24.2 (-)
/Pegel_Mic_Effekt: SW11.3, U23.6 (-), U23.7
/Pegel_Post: SW11.1, U24.6 (-), U24.7
/Pegel_Pre: SW11.4, U23.1, U23.2 (-)
GND_9V_FILT: C86.1, C89.1, C100.2, C102.2
GND_15V_FILT: C111.1, C112.1, C119.2, C120.2
GND_M: C85.2, C87.1, C88.1, C92.1, C93.1, C101.2, D4.2 (A), J34.2, J41.9, J41.10, J41.11, J41.12, R144.1, R151.1, U23.10 (+), U23.12 (+), Z238.2, Z239.2, Z240.2, Z245.2, Z246.2, Z247.2, Z248.2, Z252.2, Z253.2, Z254.2, Z256.2, Z257.2, Z260.2, Z261.2, Z262.2
GND_P: C113.2, C114.2, C117.1, C118.1, J40.9, J40.10, J40.11, J40.12, U26.5 (COM)
unnamed: C84.2, C86.2, C90.1, L1.2, Z241.1
unnamed: C85.1, H12.1
unnamed: C110.2, C111.2, C113.1, L3.2, Z255.1
unnamed: C115.1, L4.1, SW12.4
unnamed: C115.2, L4.4, SW12.2
unnamed: C117.2, C120.1, C121.2, L5.2, Z258.1
unnamed: D1.2 (A), R146.2, R147.1
unnamed: D1.1 (K), D2.2 (A), U23.14
unnamed: D2.1 (K), R145.2, R146.1, U23.13 (-)
unnamed: D4.1 (K), R148.1, R149.2
unnamed: J33.1, Z237.1, Z239.1
unnamed: J33.2, Z238.1
unnamed: C101.1, J34.1, R143.2, R144.2
unnamed: J35.1, Z244.1, Z247.1
unnamed: J35.2, Z246.1
unnamed: J36.1, Z249.1, Z253.1
unnamed: J36.2, Z252.1
unnamed: J37.1, R149.1
unnamed: J37.2, Z257.1
unnamed: J39.1, J43.1, SW12.3
unnamed: J39.2, J43.2, SW12.1
unnamed: J42.1, Z259.1, Z261.1
unnamed: J42.2, Z260.1
unnamed: R141.1, R145.1, SW11.5
unnamed: R143.1, Z243.2
unnamed: R148.2, Z251.2
unnamed: U23.3 (+), Z237.2, Z240.1
unnamed: U23.5 (+), Z244.2, Z248.1
unnamed: R141.2, R142.1, R147.2, U23.9 (-)
unnamed: U24.8, Z250.1
unnamed: U24.3 (+), Z249.2, Z254.1
unnamed: U24.5 (+), Z259.2, Z262.1
unnamed: R142.2, U23.8, U24.10 (+), U24.12 (+)
unnamed: R150.2, R151.2, U24.9 (-)
unnamed: U24.13 (-), U24.14, Z242.1
unnamed: C84.1, C89.2, C110.1, C112.2, C116.1, L4.2, U25.1 (+VIN), U26.1 (+VIN)
unnamed: L1.1, U25.6 (+VOUT)
unnamed: C100.1, C103.1, C116.2, C119.1, C121.1, L4.3, U25.2 (-VIN), U26.2 (-VIN)
unnamed: L2.1, U25.4 (-VOUT)
unnamed: L3.1, U26.6 (+VOUT)
unnamed: L5.1, U26.4 (-VOUT)
unnamed: Z242.2, Z243.1, Z245.1
unnamed: Z250.2, Z251.1, Z256.1

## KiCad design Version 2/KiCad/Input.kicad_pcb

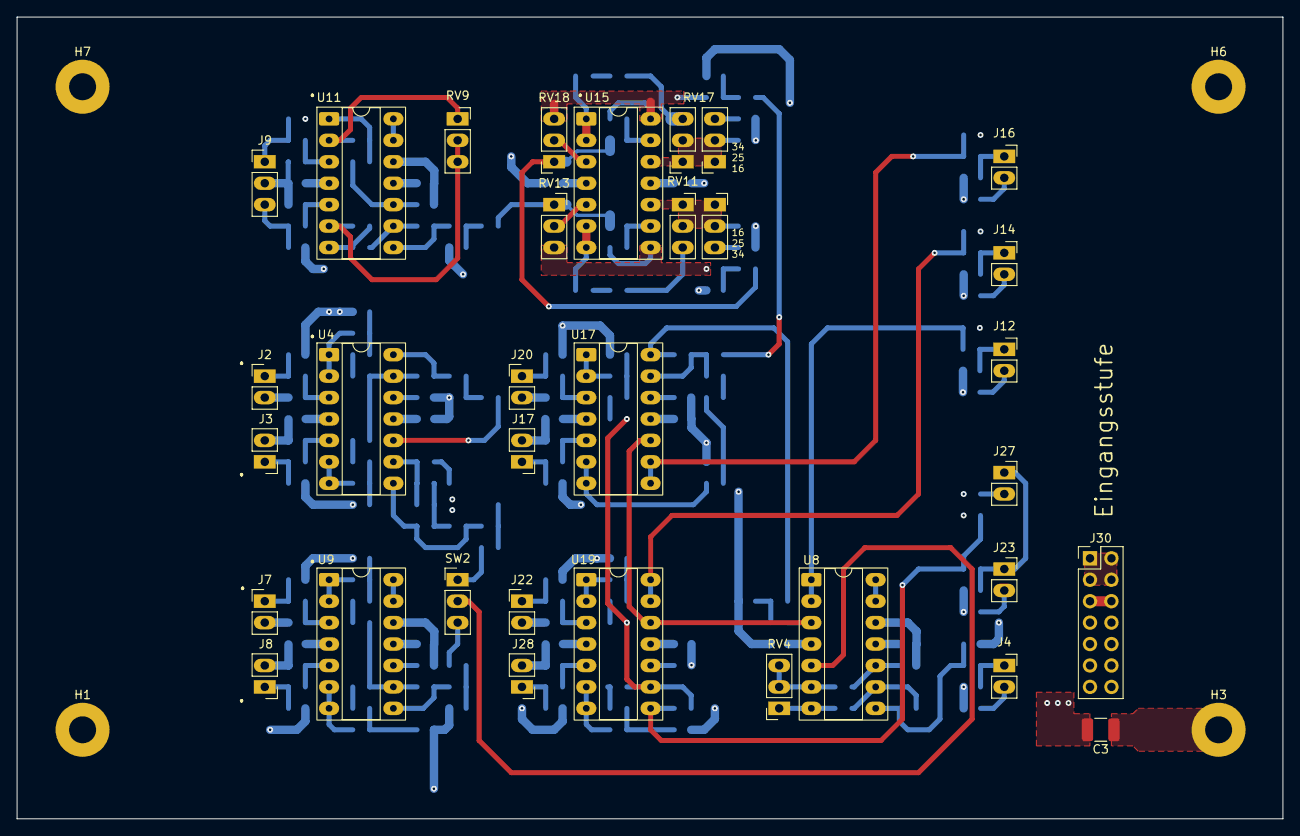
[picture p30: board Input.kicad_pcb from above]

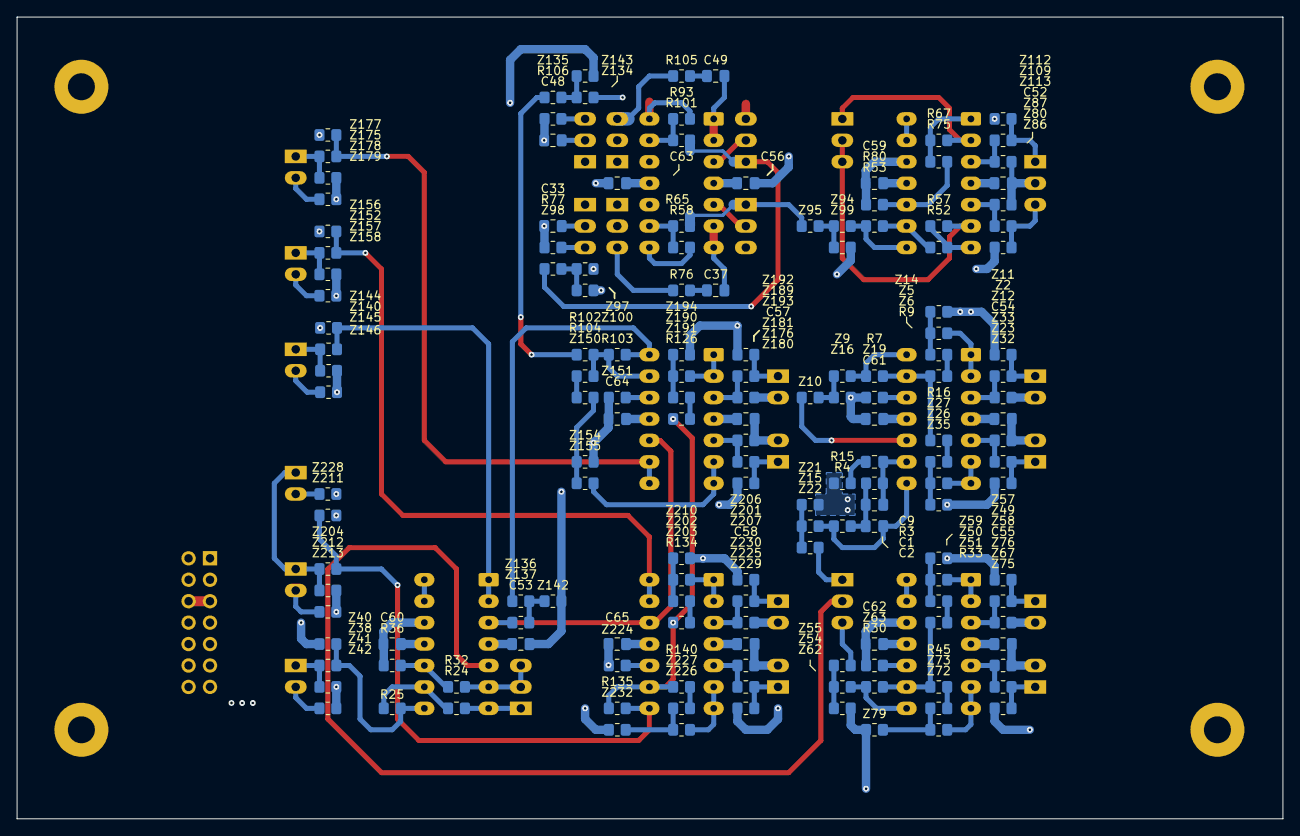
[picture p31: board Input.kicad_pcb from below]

Board: 4 copper layers, 150.0 x 95.0 mm, 190 parts (155 on the bottom side), 126 nets.

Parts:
C1: 2n2; C_0805_2012Metric_Pad1.18x1.45mm_HandSolder
C2: 10n; C_0805_2012Metric_Pad1.18x1.45mm_HandSolder
C3: 10n; C_1210_3225Metric_Pad1.33x2.70mm_HandSolder
C9: 47u; C_0805_2012Metric_Pad1.18x1.45mm_HandSolder
C33, C48: 470p; C_0805_2012Metric_Pad1.18x1.45mm_HandSolder
C37, C49: 3n; C_0805_2012Metric_Pad1.18x1.45mm_HandSolder
C52, C53, C54, C55, C56, C57, C58, C59, C60, C61, C62, C63, C64, C65: 100n; C_0805_2012Metric_Pad1.18x1.45mm_HandSolder
H1, H6, H7: MountingHole; MountingHole_3.2mm_M3_Pad
H3: MountingHole_Pad; MountingHole_3.2mm_M3_Pad
J2: R_Phono_In; PinHeader_1x02_P2.54mm_Vertical_LongPads
J3: L_Phono_In; PinHeader_1x02_P2.54mm_Vertical_LongPads
J4: Phono/Line_Out; PinSocket_1x02_P2.54mm_Vertical_LongPads
J7: R_Line_In; PinHeader_1x02_P2.54mm_Vertical_LongPads
J8: L_Line_In; PinHeader_1x02_P2.54mm_Vertical_LongPads
J9: Mic_In; PinHeader_1x03_P2.54mm_Vertical_LongPads
J12, J14, J16, J23, J27: Mic_Effekt_Out; PinSocket_1x02_P2.54mm_Vertical_LongPads
J17: AUX_RET_1; PinHeader_1x02_P2.54mm_Vertical_LongPads
J20: Effekt_In; PinHeader_1x02_P2.54mm_Vertical_LongPads
J22: AUX_RET_2; PinHeader_1x02_P2.54mm_Vertical_LongPads
J28: AUX_RET_3; PinHeader_1x02_P2.54mm_Vertical_LongPads
J30: Conn_02x07_Odd_Even; PinHeader_2x07_P2.54mm_Vertical
R3: 36k; R_0805_2012Metric_Pad1.20x1.40mm_HandSolder
R4: 390k; R_0805_2012Metric_Pad1.20x1.40mm_HandSolder
R7, R9, R16, R25, R30, R33, R45, R52, R53, R57, R67, R75, R80, R102, R103, R104, R126, R134, R135, R140: 10k; R_0805_2012Metric_Pad1.20x1.40mm_HandSolder
R15, R36: 1k; R_0805_2012Metric_Pad1.20x1.40mm_HandSolder
R24: 4k7; R_0805_2012Metric_Pad1.20x1.40mm_HandSolder
R32: 470R; R_0805_2012Metric_Pad1.20x1.40mm_HandSolder
R58, R65, R93, R101: 22k; R_0805_2012Metric_Pad1.20x1.40mm_HandSolder
R76, R77, R105, R106: 6k8; R_0805_2012Metric_Pad1.20x1.40mm_HandSolder
RV4: 50k log; PinSocket_1x03_P2.54mm_Vertical_LongPads
RV9: 10k lin; PinSocket_1x03_P2.54mm_Vertical_LongPads
RV11: 220k log; PinSocket_2x03_P2.54mm_Vertical_LongPads
RV13, RV18: 47k lin; PinSocket_1x03_P2.54mm_Vertical_LongPads
RV17: 220k log; PinSocket_2x03_P2.54mm_Vertical_LongPads_Mirrored
SW2: SW_SPDT; PinHeader_1x03_P2.54mm_Vertical_LongPads
U4, U8, U9, U11, U15, U17, U19: TL074; DIP-14_W7.62mm_Socket_LongPads
Z2, Z5, Z6, Z9, Z10, Z11, Z12, Z14, Z15, Z16, Z19, Z21, Z22, Z23, Z26, Z27, Z32, Z33, Z35, Z38, Z40, Z41, Z42, Z49, Z50, Z51, Z54, Z55, Z57, Z58, Z59, Z62, Z63, Z67, Z72, Z73, Z75, Z76, Z79, Z80, Z86, Z87, Z94, Z95, Z97, Z98, Z99, Z100, Z109, Z112, Z113, Z134, Z135, Z136, Z137, Z140, Z142, Z143, Z144, Z145, Z146, Z150, Z151, Z152, Z154, Z155, Z156, Z157, Z158, Z175, Z176, Z177, Z178, Z179, Z180, Z181, Z189, Z190, Z191, Z192, Z193, Z194, Z201, Z202, Z203, Z204, Z206, Z207, Z210, Z211, Z212, Z213, Z224, Z225, Z226, Z227, Z228, Z229, Z230, Z232: R_0805_2012Metric_Pad1.20x1.40mm_HandSolder

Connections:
9V_GND_I: J30.1, J30.2, J30.3, J30.4
+9V_I: J30.5, J30.6
+15V_I: C52.1, C53.2, C54.2, C55.2, C56.2, C57.2, C58.2, J30.13, J30.14, U4.4 (V+), U8.4 (V+), U9.4 (V+), U11.4 (V+), U15.4 (V+), U17.4 (V+), U19.4 (V+)
-15V_I: C59.2, C60.2, C61.2, C62.2, C63.2, C64.2, C65.2, J30.7, J30.8, U4.11 (V-), U8.11 (V-), U9.11 (V-), U11.11 (V-), U15.11 (V-), U17.11 (V-), U19.11 (V-)
GND_I: C3.2, C33.2, C48.2, C52.2, C53.1, C54.1, C55.1, C56.1, C57.1, C58.1, C59.1, C60.1, C61.1, C62.1, C63.1, C64.1, C65.1, J2.2, J3.2, J7.2, J8.2, J9.2, J17.2, J20.2, J22.2, J28.2, J30.9, J30.10, J30.11, J30.12, R15.1, R36.1, R77.1, R80.1, R106.1, U8.12 (+), U9.12 (+), U11.12 (+), Z11.2, Z12.2, Z14.2, Z16.2, Z19.2, Z21.2, Z32.2, Z33.2, Z35.2, Z40.2, Z41.2, Z42.2, Z57.2, Z58.2, Z59.2, Z62.2, Z63.2, Z75.2, Z76.2, Z79.2, Z86.2, Z87.2, Z99.2, Z100.2, Z112.2, Z113.2, Z142.2, Z143.1, Z144.2, Z145.2, Z146.2, Z151.2, Z154.2, Z156.2, Z157.2, Z158.2, Z177.2, Z178.2, Z179.2, Z180.2, Z181.2, Z192.2, Z193.2, Z194.2, Z206.2, Z207.2, Z210.2, Z211.2, Z212.2, Z213.2, Z224.2, Z228.2, Z229.2, Z230.2, Z232.2
unnamed: C1.2, C2.1, R3.1, R4.2
unnamed: C2.2, R4.1, U4.8, Z15.1
unnamed: C3.1, H3.1
unnamed: C9.1, R15.2
unnamed: C37.1, R76.1
unnamed: C49.1, R105.1
unnamed: J2.1, Z2.1, Z11.1
unnamed: J3.1, Z23.1, Z32.1
unnamed: J4.1, Z38.2, Z41.1
unnamed: J4.2, Z42.1
unnamed: J7.1, Z49.1, Z57.1
unnamed: J8.1, Z67.1, Z75.1
unnamed: J9.1, Z109.1, Z112.1
unnamed: J9.3, Z80.1, Z86.1
unnamed: J12.1, Z140.2, Z145.1
unnamed: J12.2, Z146.1
unnamed: J14.1, Z152.2, Z157.1
unnamed: J14.2, Z158.1
unnamed: J16.1, Z175.2, Z178.1
unnamed: J16.2, Z179.1
unnamed: J17.1, Z176.1, Z180.1
unnamed: J20.1, Z189.1, Z192.1
unnamed: J22.1, Z201.1, Z206.1
unnamed: J23.1, J27.1, Z204.2, Z212.1
unnamed: J23.2, Z213.1
unnamed: J27.2, Z228.1
unnamed: J28.1, Z225.1, Z229.1
unnamed: R7.2, U4.14, Z9.1
unnamed: R9.1, Z6.2
unnamed: R16.1, Z27.2
unnamed: R24.1, RV4.1, U8.7
unnamed: R25.2, U8.8, Z38.1, Z40.1
unnamed: R30.2, U9.8, Z54.1
unnamed: R33.1, Z51.2
unnamed: R45.1, Z73.2
unnamed: R52.1, R57.2, U11.7
unnamed: R53.1, U11.8, Z94.1
unnamed: R58.2, RV13.3, U15.8, Z97.1
unnamed: R65.1, RV13.1, Z95.2
unnamed: R67.1, R75.1, U11.1
unnamed: R76.2, RV11.3
unnamed: R77.2, RV11.4
unnamed: R93.2, RV18.3, U15.14, Z134.1
unnamed: R101.1, RV18.1, Z98.2
unnamed: R102.1, Z135.2
unnamed: R103.2, U17.14, Z136.1
unnamed: R104.1, Z150.1
unnamed: R105.2, RV17.3
unnamed: R106.2, RV17.4
unnamed: R126.2, Z191.2
unnamed: R134.2, Z203.2
unnamed: R135.1, U19.8, Z204.1, Z211.1
unnamed: R140.2, Z227.2
unnamed: SW2.1 (A), Z22.2
unnamed: SW2.2 (B), U8.5 (+)
unnamed: SW2.3 (C), Z55.2
unnamed: U4.3 (+), Z2.2, Z12.1
unnamed: U4.1, U4.2 (-), Z5.1
unnamed: U4.5 (+), Z23.2, Z33.1
unnamed: U4.6 (-), U4.7, Z26.1
unnamed: U4.10 (+), Z10.2
unnamed: C1.1, C9.2, R3.2, U4.9 (-)
unnamed: U4.12 (+), Z19.1
unnamed: R7.1, R9.2, R16.2, U4.13 (-)
unnamed: U8.1, U8.2 (-), Z140.1, Z144.1
unnamed: R32.1, RV4.2, RV4.3, U8.6 (-)
unnamed: R32.2, R36.2, U8.10 (+)
unnamed: R24.2, R25.1, U8.9 (-)
unnamed: U8.13 (-), U8.14
unnamed: U9.3 (+), Z49.2, Z58.1
unnamed: U9.1, U9.2 (-), Z50.1
unnamed: U9.5 (+), Z67.2, Z76.1
unnamed: U9.6 (-), U9.7, Z72.1
unnamed: U9.10 (+), Z63.1
unnamed: R30.1, R33.2, R45.2, U9.9 (-)
unnamed: U9.13 (-), U9.14
unnamed: U11.3 (+), Z109.2, Z113.1
unnamed: R67.2, RV9.1, U11.2 (-)
unnamed: U11.5 (+), Z80.2, Z87.1
unnamed: R57.1, RV9.2, RV9.3, U11.6 (-)
unnamed: R75.2, R80.2, U11.10 (+)
unnamed: R52.2, R53.2, U11.9 (-)
unnamed: U11.13 (-), U11.14
unnamed: RV18.2, U15.3 (+)
unnamed: C49.2, U15.1, U15.2 (-)
unnamed: RV13.2, U15.5 (+)
unnamed: C37.2, U15.6 (-), U15.7
unnamed: C33.1, RV11.1, RV11.2, RV11.5, RV11.6, U15.10 (+)
unnamed: R58.1, R65.2, U15.9 (-)
unnamed: C48.1, RV17.1, RV17.2, RV17.5, RV17.6, U15.12 (+)
unnamed: R93.1, R101.2, U15.13 (-)
unnamed: U17.3 (+), Z189.2, Z193.1
unnamed: U17.1, U17.2 (-), Z190.1
unnamed: U17.5 (+), Z176.2, Z181.1
unnamed: U17.6 (-), U17.7, Z155.2
unnamed: U8.3 (+), U17.10 (+), U19.12 (+), Z137.2
unnamed: U17.8, U17.9 (-), Z175.1, Z177.1
unnamed: U17.12 (+), Z151.1
unnamed: R102.2, R103.1, R104.2, U17.13 (-)
unnamed: U19.3 (+), Z201.2, Z207.1
unnamed: U19.1, U19.2 (-), Z202.1
unnamed: U19.5 (+), Z225.2, Z230.1
unnamed: U19.6 (-), U19.7, Z226.1
unnamed: U19.10 (+), Z224.1
unnamed: R126.1, R134.1, R135.2, R140.1, U19.9 (-)
unnamed: U19.13 (-), U19.14, Z152.1, Z156.1
unnamed: Z9.2, Z10.1, Z16.1
unnamed: Z5.2, Z6.1, Z14.1
unnamed: Z15.2, Z21.1, Z22.1
unnamed: Z26.2, Z27.1, Z35.1
unnamed: Z50.2, Z51.1, Z59.1
unnamed: Z54.2, Z55.1, Z62.1
unnamed: Z72.2, Z73.1, Z79.1
unnamed: Z94.2, Z95.1, Z99.1
unnamed: Z97.2, Z98.1, Z100.1
unnamed: Z134.2, Z135.1, Z143.2
unnamed: Z136.2, Z137.1, Z142.1
unnamed: Z150.2, Z154.1, Z155.1
unnamed: Z190.2, Z191.1, Z194.1
unnamed: Z202.2, Z203.1, Z210.1
unnamed: Z226.2, Z227.1, Z232.1

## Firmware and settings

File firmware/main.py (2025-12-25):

# NOTE: Will start making firmware when i get approved  

print("Starting")

import board

from kmk.kmk_keyboard import KMKKeyboard
from kmk.keys import KC
from kmk.scanners import DiodeOrientation
from kmk.modules.encoder import EncoderHandler
from kmk.extensions.media_keys import MediaKeys

keyboard = KMKKeyboard()

keyboard.col_pins = (board.GP26, board.GP27, board.GP28, board.GP29)
keyboard.row_pins = (board.GP3, board.GP4, board.GP2, board.GP1)
keyboard.diode_orientation = DiodeOrientation.COL2ROW

encoder = EncoderHandler()
encoder.pins = (
    (board.GP7, board.GP6, None),  
)
encoder.map = [
    ((KC.VOLD, KC.VOLU, KC.NO),),  
]
keyboard.modules.append(encoder)
keyboard.extensions.append(MediaKeys())

keyboard.keymap = [
    [
        KC.N1, KC.N2, KC.N3, KC.MUTE,   
        KC.N4, KC.N5, KC.N6, KC.N7,     
        KC.N8, KC.N9, KC.N0, KC.ENT,    
        KC.A,  KC.B,  KC.C,  KC.D,      
    ],
]

if __name__ == "__main__":
    keyboard.go()

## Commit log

2025-12-16 feat: add pcband keyboard layout
    [MX .STEP, Seeed Studio XIAO RP2040 v26.step, SplitKeeb.kicad_pcb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]
2025-12-20 update pcb
    [SplitKeeb.kicad_pcb, SplitKeeb.kicad_sch]
2025-12-20 update left pcb
    [SplitKeeb.kicad_pcb, SplitKeeb.kicad_sch, left_side.kicad_sch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]
2025-12-22 complete right againnn with HolyIOT 18010
    [LED_SK6812MINI-E.step, Left.kicad_pcb, Left.kicad_sch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]
2025-12-23 add pcb graphics
2025-12-23 add bom
    [SplitKeeb Bill of Materials.xlsx, SplitKeeb.csv]
2025-12-23 update, add prod
    [bom.csv, designators.csv, positions.csv]
2025-12-23 remove old bom
    [bom.csv]
2025-12-24 update bom add images
    [Combined.kicad_sch, Left.kicad_sch, SplitKeeb.csv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]
2025-12-24 update bom
    [RobuBom.csv, SplitKeeb.csv]
2025-12-25 add dummy firmware
    [RobuExported.xlsx]
